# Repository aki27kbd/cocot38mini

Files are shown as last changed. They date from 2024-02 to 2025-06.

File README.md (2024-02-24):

# cocot38mini

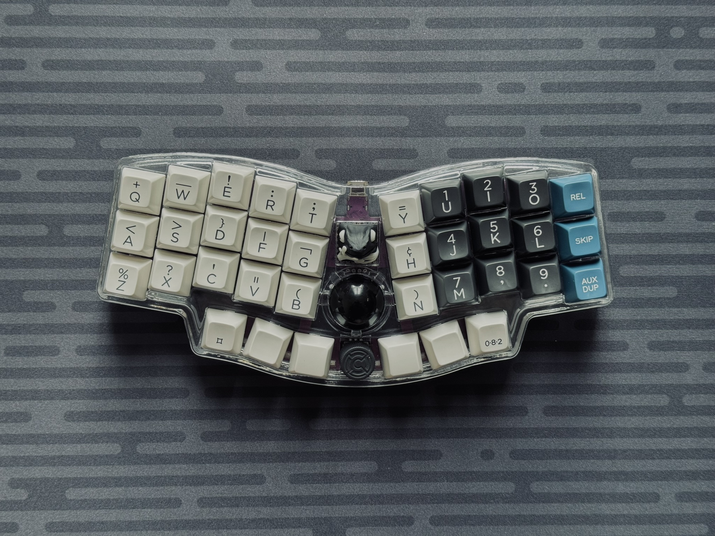
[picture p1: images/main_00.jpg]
cocot38mini_main00


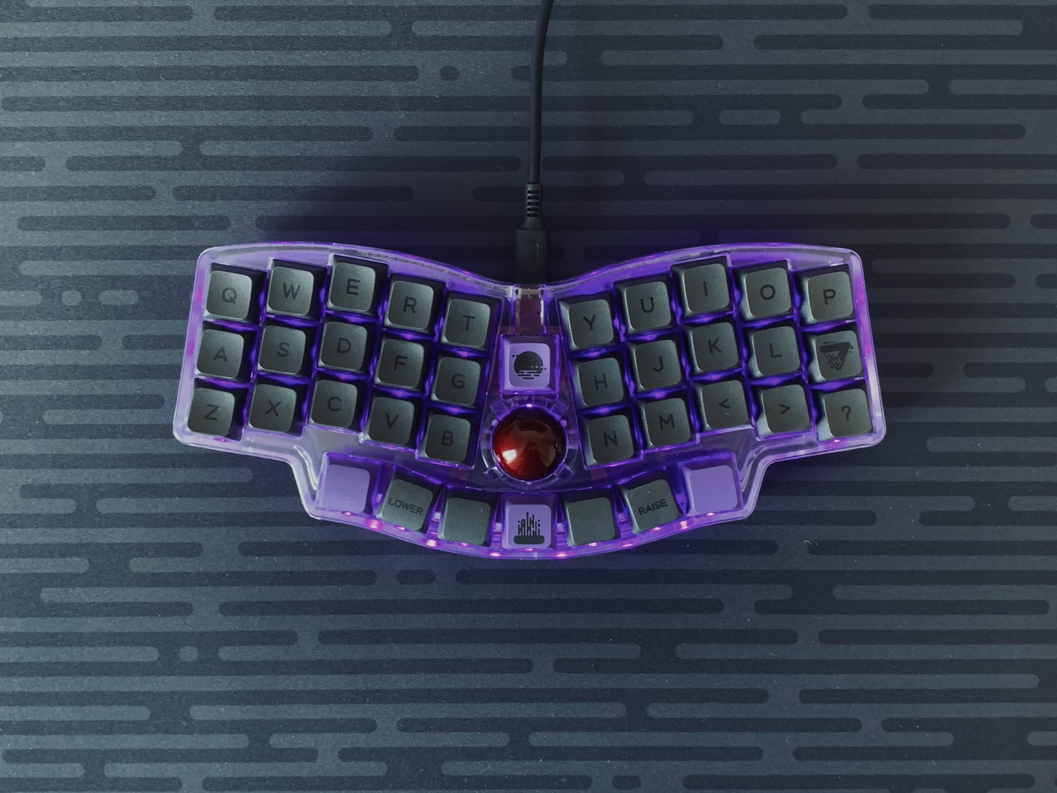
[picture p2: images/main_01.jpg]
cocot38mini_main01


cocot38mini is a compact column staggered keyboard with 38 keys and a 25mm-trackball.

- Keyboard Maintainer: [aki27kbd](https://github.com/aki27kbd) [@aki27kbd](https://twitter.com/aki27kbd)
- Hardware Supported: cocot38mini PCB
- Hardware Availability: [cocotkeebs](https://cocotkeebs.com)

Build Guide [JP](doc/buildguide.md) / [EN](doc/buildguide_en.md)

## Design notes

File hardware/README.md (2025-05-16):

# cocot38mini Case Guide

cocot38miniはマウント方式、ボール保持方式、ボール支持方式に応じて様々な種類のケースオプションを用意しています。このガイドにある各種方式の説明を参考に、お好みのケースを作成してください。

cocot38mini_main00

# Mounting Method

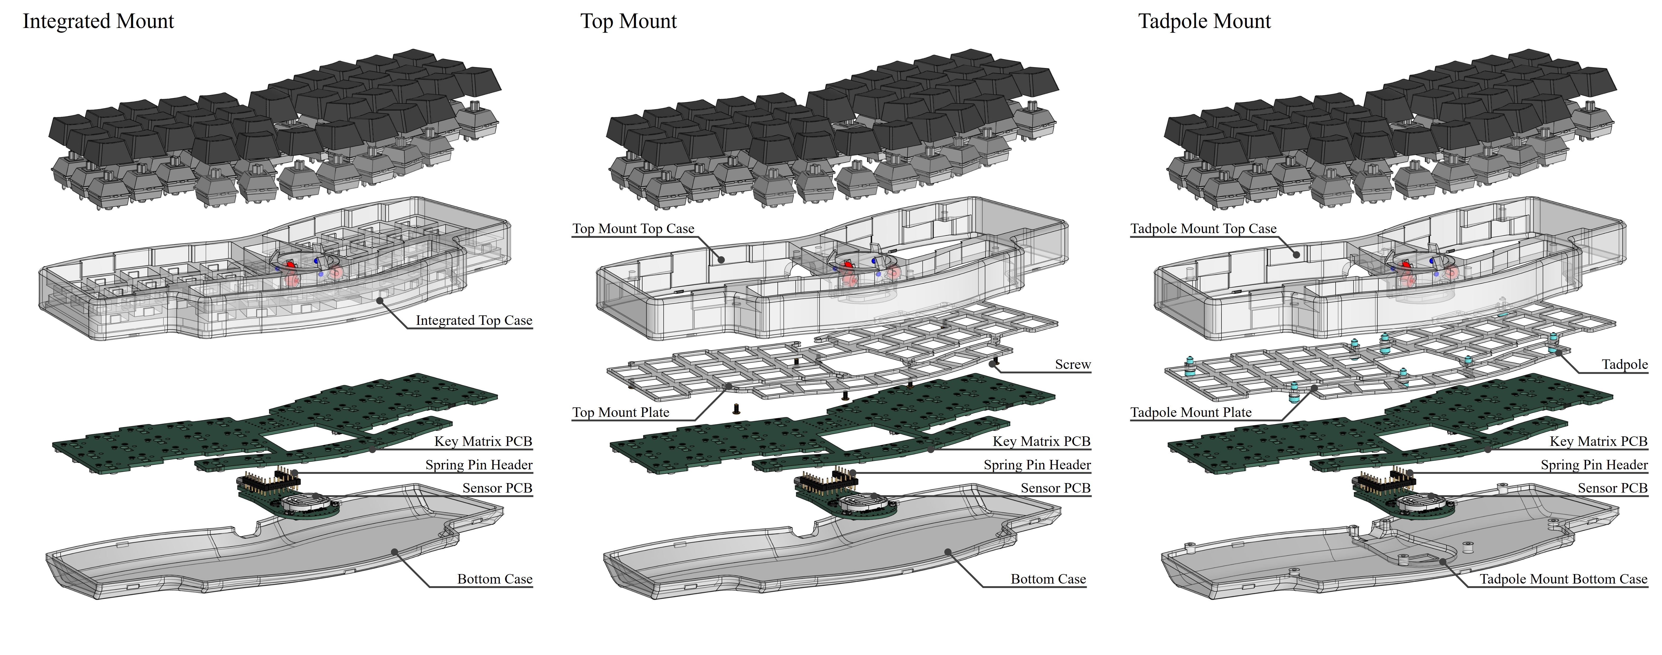
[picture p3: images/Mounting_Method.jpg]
mounting_method


### Integrated
プレートインテグレーテッドマウントは部品点数が最も少ない方式です。プレートの厚みが5mmでかつケース構造と一体化されているので、比較的硬い打鍵感となっています。

|Parts|Qty|Note|
|---|---|---|
|3Dプリントトップケース|1|"_integrated"が含まれるトップケース|
|3Dプリントボトムケース|1|cocot38mini_v2_bottom.stp|

### Top Mount
トップマウントはプレートをトップケースにねじ止めする方式です。トップケースに熱圧入インサートナットを埋め込む必要があるので、組み立て難易度は比較的高めです。プレートの材質や厚みを変更することで打鍵感を調整することが可能です。   
**熱圧入インサートナットはSLA（レジン）への固定に適しません。レジンのケースを作成する場合は、接着剤等でインサートナットを固定してください。**

|Parts|Qty|Note|
|---|---|---|
|3Dプリントトップケース|1|"_topmount"が含まれるトップケース|
|3Dプリントスイッチプレート|1|"_topmount"が含まれるプレート|
|3Dプリントボトムケース|1|cocot38mini_v2_bottom.stp|
|熱圧入インサートナット|8|[HFB-2001](https://hirosugi.co.jp/products/B/HFB.html#bx1)|
|M2ねじ3mm|8||

### Tadpole Mount
タッドポールマウントはシンプルな構造と良好な打鍵感のバランスが特徴の方式です。タッドポールの硬さを変更することで打鍵感の調整が可能です。

|Parts|Qty|Note|
|---|---|---|
|3Dプリントトップケース|1|"_tadpole"が含まれるトップケース|
|3Dプリントスイッチプレート|1|"_tadpole"が含まれるプレート|
|3Dプリントボトムケース|1|cocot38mini_v2_tadpole_bottom.stp|
|Tadpole|8|Available at [GEONWORKS](https://geon.works/products/tadpole) or [GREENKEYS](https://shop.green-keys.info/products/tadpole)|

# Ball Supporting Method

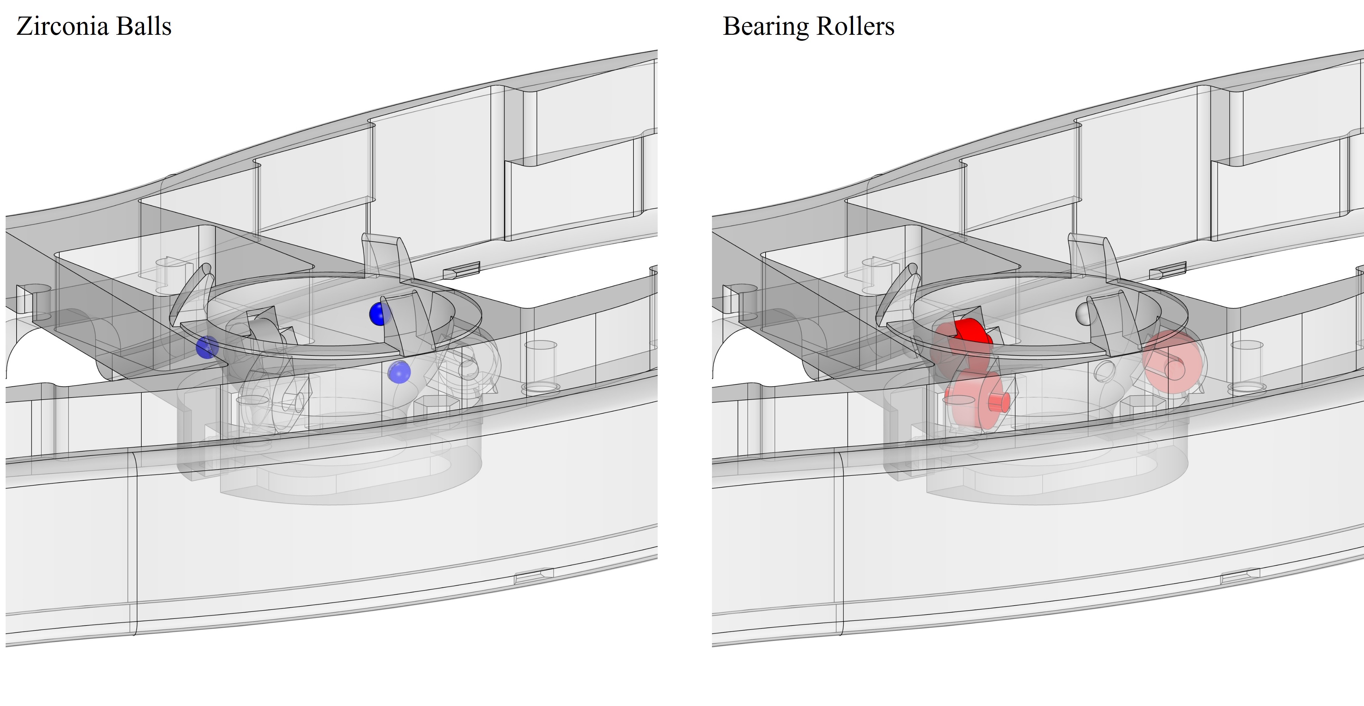
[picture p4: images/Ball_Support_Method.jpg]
ball_support_method


### Zirconia Balls
2mmジルコニア球によるボール支持方式です。キットにジルコニア球が含まれている場合、追加のバーツは必要ありません。ジルコニア球を接着剤で固定した場合、ベアリングとの共存はできません。

|Parts|Qty|Note|
|---|---|---|
|ジルコニア球|3|Φ2mm|

### Bearing Rollers
ベアリングローラーによるボール支持方式です。スムーズな操球が可能です。   
組み立て方法は[picot5400](https://github.com/aki27kbd/picot5400/blob/main/doc/buildguide.md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)を参照してください。

|Parts|Qty|Note|
|---|---|---|
|ベアリングローラー|3|ID:3mm x OD:6mm x W:2.5mm|
|ステンレス棒|3|Φ2mm x L:6mm|
|シリコンチューブ|1|ID: 2mm x OD:3mm|

# Ball Holding Method

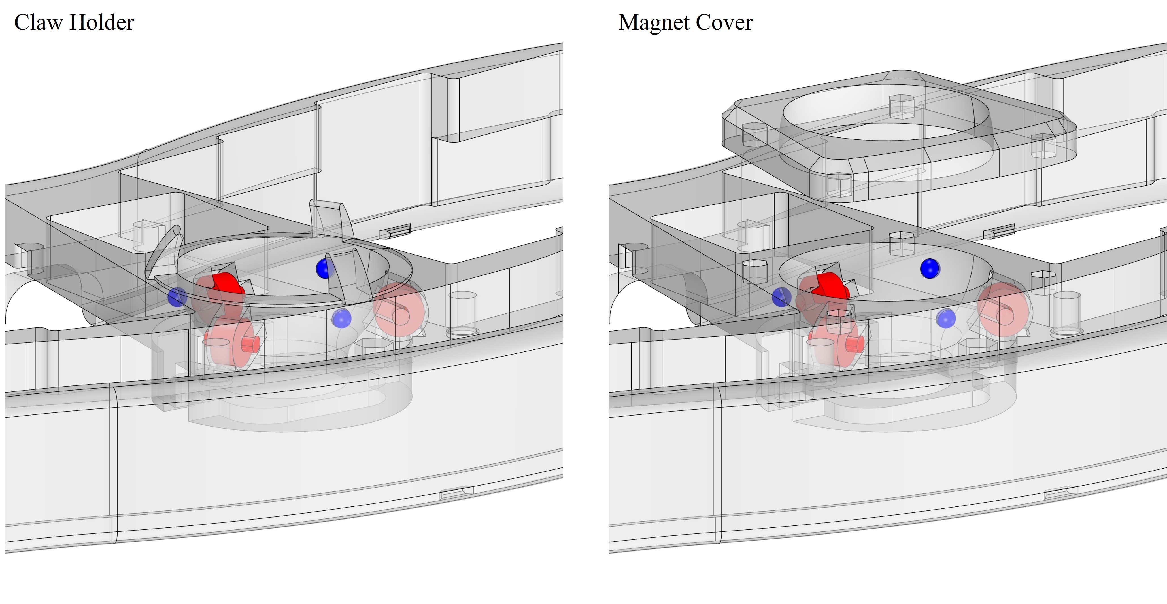
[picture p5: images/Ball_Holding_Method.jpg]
ball_holding_method


### Claw Holder
3本のツメでボールが落下しないようにするケースです。  
**FDM方式のプリンターでケースを作成した場合、ツメが破損しやすくなるためお勧めいたしません。**

|Parts|Qty|Note|
|---|---|---|
|3Dプリントトップケース|1|"_claw"が含まれるトップケース|

### Magnet Cover
マグネットによってボールカバーをトップケースに固定する方式です。容易にボールの取り外しが可能です。

|Parts|Qty|Note|
|---|---|---|
|3Dプリントトップケース|1|"_magnet"が含まれるトップケース|
|3Dプリントボールカバー|1|cocot38mini_v2_ballcover.stp|
|マグネット|8|Φ3mm x H:2mm|

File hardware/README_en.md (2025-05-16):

# cocot38mini Case Guide

cocot38mini provides various case data depending on mounting methods, ball support styles and ball holding geometries. This guide shows the overview of each method, including pros/cons as well as BOM of it.

cocot38mini_main00

# Mounting Method

mounting_method

### Integrated
Plate-integrated mount is the simplest mounting method with fewer parts required to assemble. No additional parts are required to build this case. As the plate is thick and integrated with the case structure, it provides a solid feeling relative to other mounting methods.

|Parts|Qty|Note|
|---|---|---|
|3D Printed Top Case|1|Top case named with "_integrated"|
|3D Printed Bottom Case|1|cocot38mini_v2_bottom.stp|

### Top Mount
Top mount is the general mounting method which is also used for some of custom keyboards. Assembly is relatively difficult due to the need of heated insert nuts. Typing softness can be adjusted depending on the plate material.   
**SLA (Resin) is not suitable for heated insert nut. If you use it as a case material, make sure you fix insert nuts with glue.**

|Parts|Qty|Note|
|---|---|---|
|3D Printed Top Case|1|Top case named with "_topmount"|
|3D Printed Switch Plate|1|Plate named with "_topmount"|
|3D Printed Bottom Case|1|cocot38mini_v2_bottom.stp|
|Heated Insert Nut|8|[HFB-2001](https://hirosugi.co.jp/products/B/HFB.html#bx1)|
|M2 Screw 3mm|8||

### Tadpole Mount
Tadpole mount is designed considering the balance of simple structure and better typing feel. Assembly is relatively easy as long as tadpoles are available. Typing softness can be adjusted depending on the hardness of tadpoles.

|Parts|Qty|Note|
|---|---|---|
|3D Printed Top Case|1|Top case named with "_tadpole"|
|3D Printed Switch Plate|1|Plate named with "_tadpole"|
|3D Printed Bottom Case|1|cocot38mini_v2_tadpole_bottom.stp|
|Tadpole|8|Available at [GEONWORKS](https://geon.works/products/tadpole) or [GREENKEYS](https://shop.green-keys.info/products/tadpole)|

# Ball Supporting Method

ball_support_method

### Zirconia Balls
3x Φ2mm zirconia balls support the ball. No additional parts needed. Once zirconia balls are installed, <u>**bearing rollers can not coexist with them**</u>.

|Parts|Qty|Note|
|---|---|---|
|Zirconia Ball|3|Φ2mm|

### Bearing Rollers
3x bearing rollers support the ball. Ball handling is smoother with less resistance. Bearing roller dimension is ID: 3mm / OD: 6mm / W: 2.5mm.　　　
Refer to [picot5400](https://github.com/aki27kbd/picot5400/blob/main/doc/buildguide_en.md#ball-case) for assembly.

|Parts|Qty|Note|
|---|---|---|
|Bearing Roller|3|ID:3mm x OD:6mm x W:2.5mm|
|Steel Pin|3|Φ2mm x L:6mm|
|Silicon Tube|1|ID: 2mm x OD:3mm|

# Ball Holding Method

ball_holding_method

### Claw Holder
Claw holder is integrated with the top case and no additional parts needed. Due to the thin structure, it is <u>**not recommended**</u> printing this model with FDM printers.

|Parts|Qty|Note|
|---|---|---|
|3D Printed Top Case|1|Top case named with "_claw"|

### Magnet Cover
Magnet cover is an additional part attached to the top case with magnets. Depending on case clearance, glue might be needed to fix magnets.

|Parts|Qty|Note|
|---|---|---|
|3D Printed Top Case|1|Top case named with "_magnet"|
|3D Printed Ball Cover|1|cocot38mini_v2_ballcover.stp|
|Magnet|8|Φ3mm x H:2mm|

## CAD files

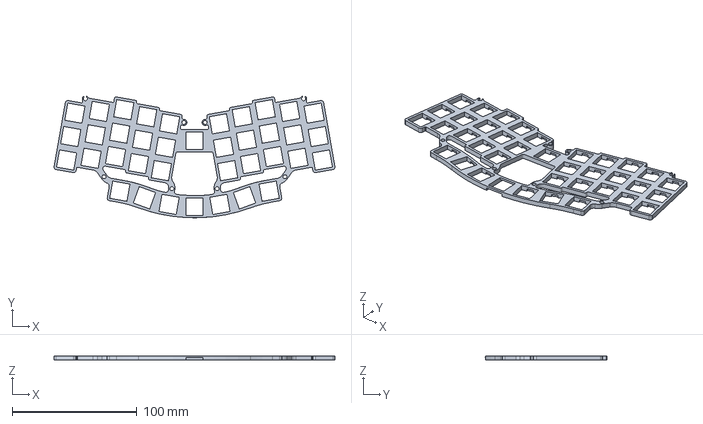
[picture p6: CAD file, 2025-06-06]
hardware/cocot38mini_v2_tadpole_plate_thick.stp
225.0 x 97.4 x 3.50 mm

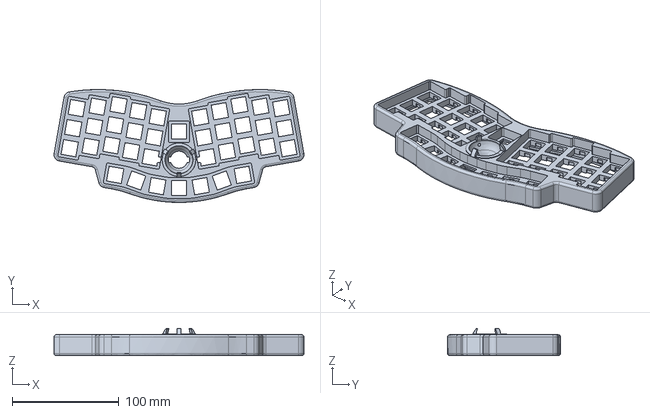
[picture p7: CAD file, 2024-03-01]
hardware/v1/cocot38mini_top_v1.stp
234.2 x 105.7 x 25.5 mm

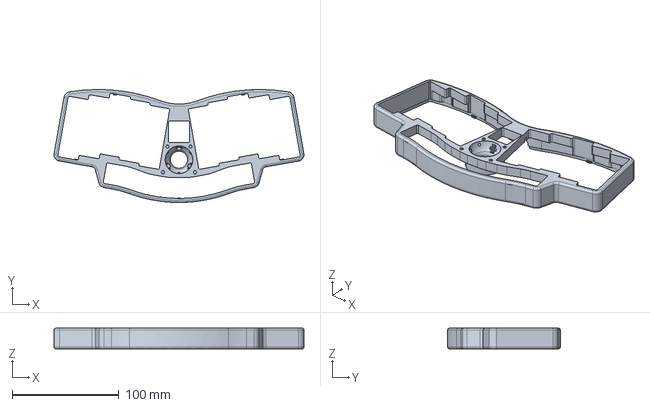
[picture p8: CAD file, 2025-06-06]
hardware/cocot38mini_v2_tadpole_top_magnet_Lsnap.stp
234.2 x 105.8 x 19.6 mm

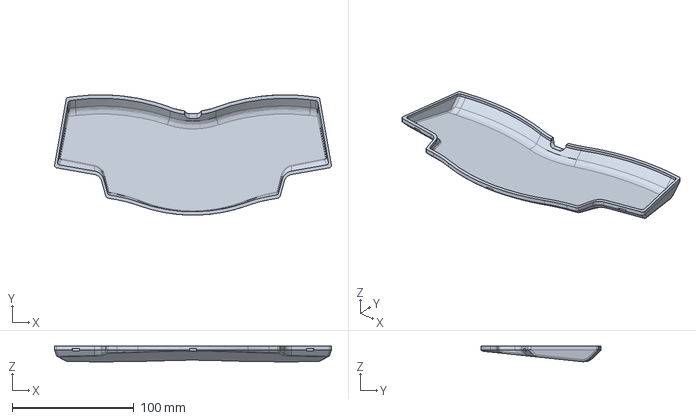
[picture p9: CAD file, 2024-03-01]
hardware/v1/cocot38mini_bottom_v1.stp
227.4 x 98.8 x 12.8 mm

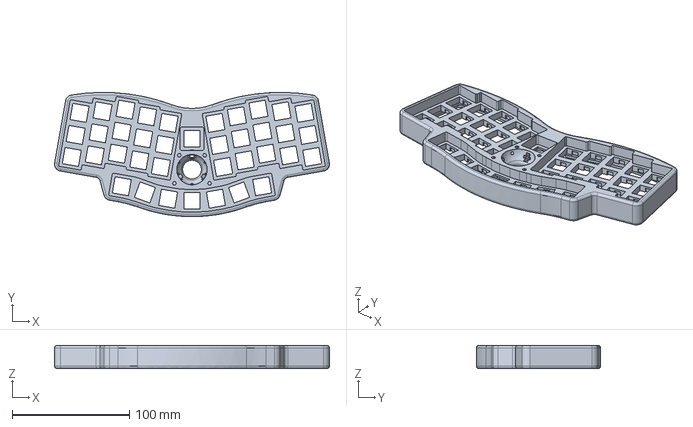
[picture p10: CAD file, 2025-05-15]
hardware/cocot38mini_v2_integrated_top_magnet.stp
234.2 x 105.8 x 19.6 mm

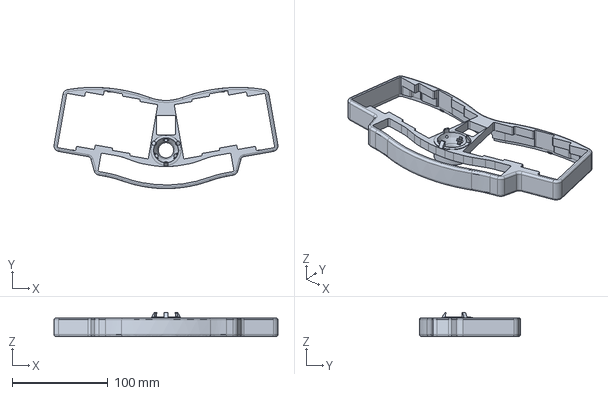
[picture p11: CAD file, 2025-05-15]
hardware/cocot38mini_v2_topmount_top_claw.stp
234.2 x 105.7 x 25.2 mm

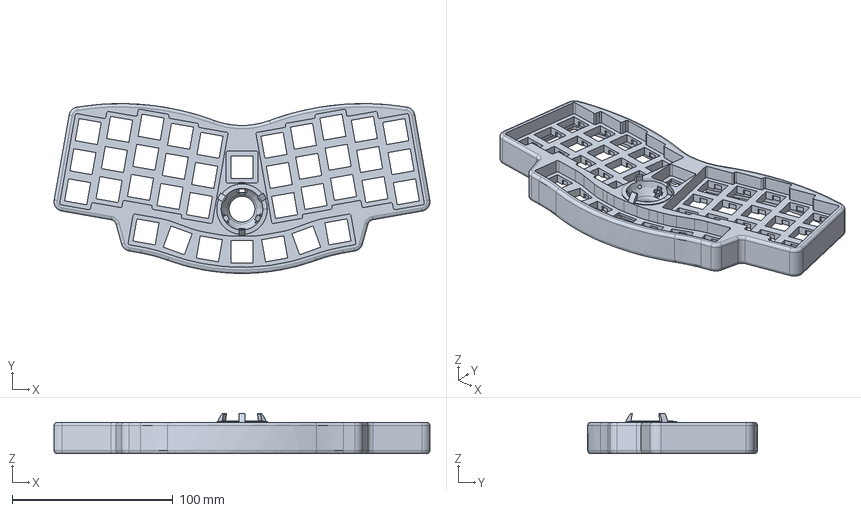
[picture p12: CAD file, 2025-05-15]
hardware/cocot38mini_v2_integrated_top_claw.stp
234.2 x 105.7 x 25.2 mm

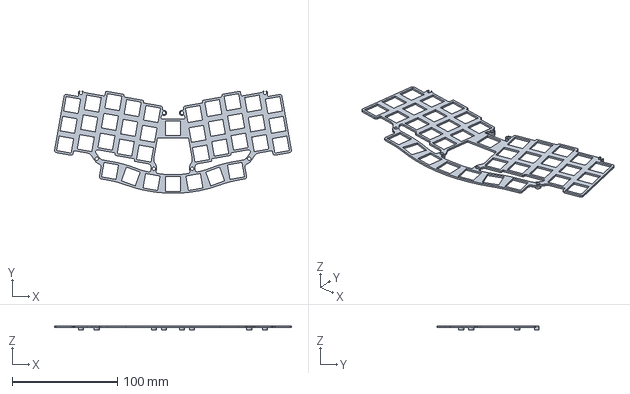
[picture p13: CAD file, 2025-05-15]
hardware/cocot38mini_v2_tadpole_plate.stp
225.0 x 97.3 x 3.50 mm

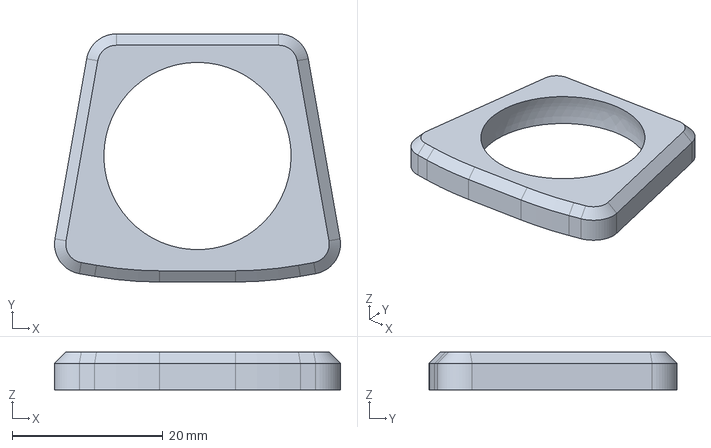
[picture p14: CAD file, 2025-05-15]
hardware/cocot38mini_v2_ballcover.stp
38.0 x 33.0 x 5.00 mm

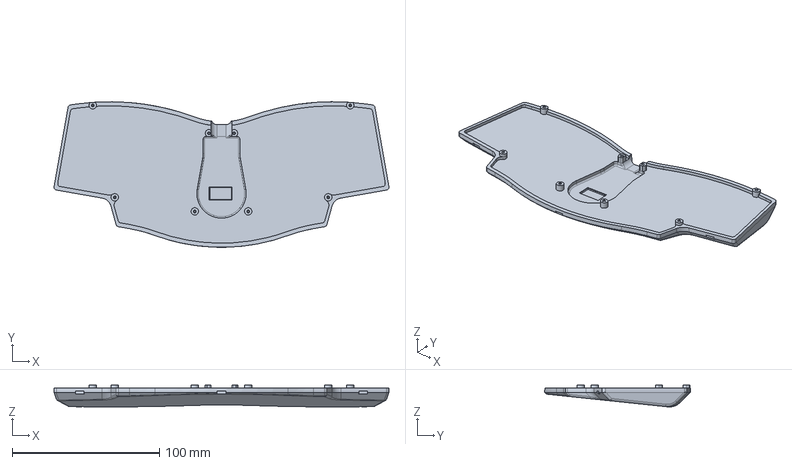
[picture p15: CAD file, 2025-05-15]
hardware/cocot38mini_v2_tadpole_bottom.stp
227.4 x 98.8 x 14.8 mm

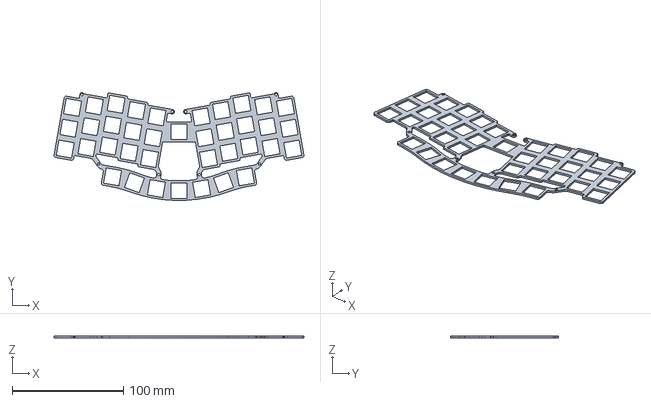
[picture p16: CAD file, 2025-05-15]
hardware/cocot38mini_v2_topmount_plate.stp
225.0 x 97.0 x 1.50 mm

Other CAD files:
hardware/cocot38mini_v2_bottom.stp
hardware/cocot38mini_v2_topmount_top_magnet.stp
hardware/cocot38mini_v2_tadpole_top_claw.stp
hardware/cocot38mini_v2_tadpole_top_magnet.stp

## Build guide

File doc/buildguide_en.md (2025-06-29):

# Build Guide

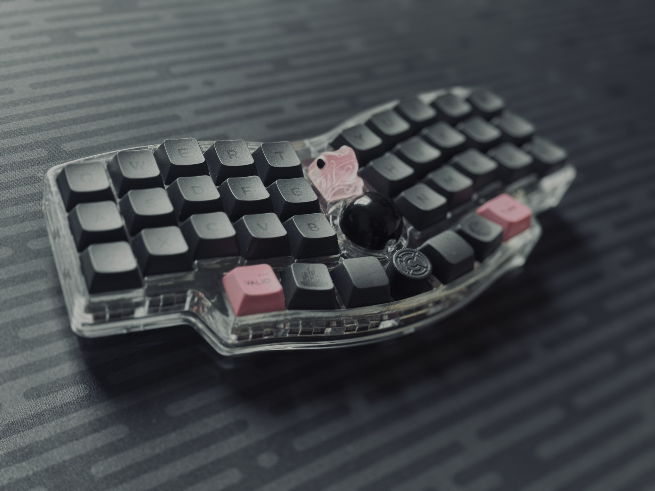
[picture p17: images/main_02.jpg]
cocot38mini_main02


This is a buildguide for cocot38mini v2.  
For v1 buildguide, refer to the previous documents ([JP](v1/buildguide.md) / [EN](v1/buildguide_en.md))

cocot38mini is designed as a more compact version of cocot series, with column-staggered 38 keys, 25mm trackbvall and 3D printed case. To begin with, please make sure you read this buildguide carefully and you have everything you need before you start to asseble.

## Parts
### Parts Included

|Parts|Qty|Notes|
|---|---|---|
|PCB|1||
|Sensor PCB|1||
|Sensor (PMW3360)|1||
|Rubber Feet|4||
|Zirconia Balls (2mm)|3||

### Additional Required Parts

|Parts|Qty|Notes|
|---|---|---|
|3D Printed Case (Top+Bottom)|1|You can download 3d data to order 3d printing service by yourself|
|Keyswitch|37 or 38|MX|
|Keycap|37 or 38|MX|
|Rotary Encoder + Knob |1|Optional|
|Spring Pin Header or Pin Header (H2.5mm)|At least 20 pins are necessary||
|25mm Trackball|1||
|Bearing Roller|3|Optional (Bearing Roller Support)|
|Tadpole|8|Optional (Tadpole Mount)|
|Heated Insert Nut|8|Optional (Top Mount)|
|M2 Screw 3mm|8|Optional (Top Mount)|
|USB-Type C Cable|1||

## Assembly
### Parts Check

  First, please make sure that you have all the parts listed above. If the PCB comes with tabs, break off the tabs and lightly file the cut surfaces.

### Firmware

  It is delivered with the default firmware is written. Before starting soldering, make sure you confirm the sensor PCB is recognized as cocot38mini when you plug USB to it.

  If you wish to write your own firmware, please follow the instructions below.

  - Press the RESET button (SW39) while holding down the BOOT button (SW40) on the bottom side to enter boot loader mode.
  - The firmware is written by dragging and dropping the [.uf2](https://github.com/aki27kbd/cocot38mini/blob/main/firmware/aki27_cocot38mini_v2_vial.uf2) file into the drive named RPI-RP2.  
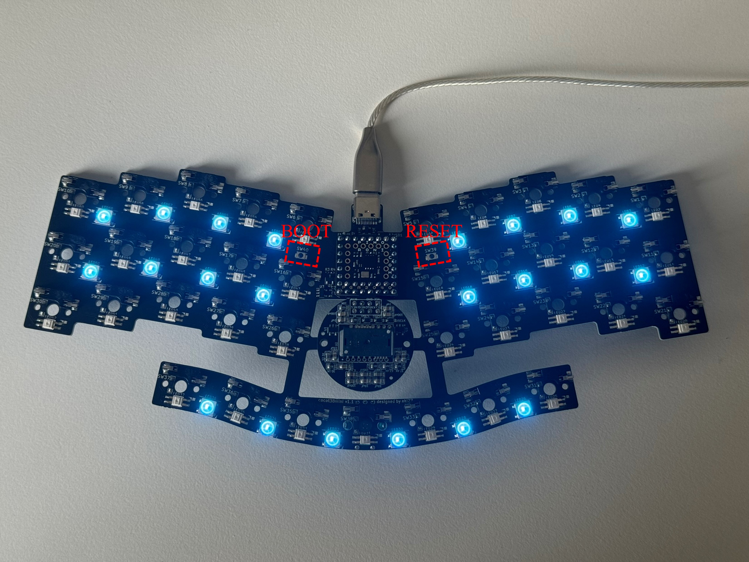
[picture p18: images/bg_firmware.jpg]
    

  Keymap is editable from [vial](https://vial.rocks/).  
  You can confirm that trackball and LEDs are working correctly with this firmware. You can confirm the trackball move after you assemble the following steps.

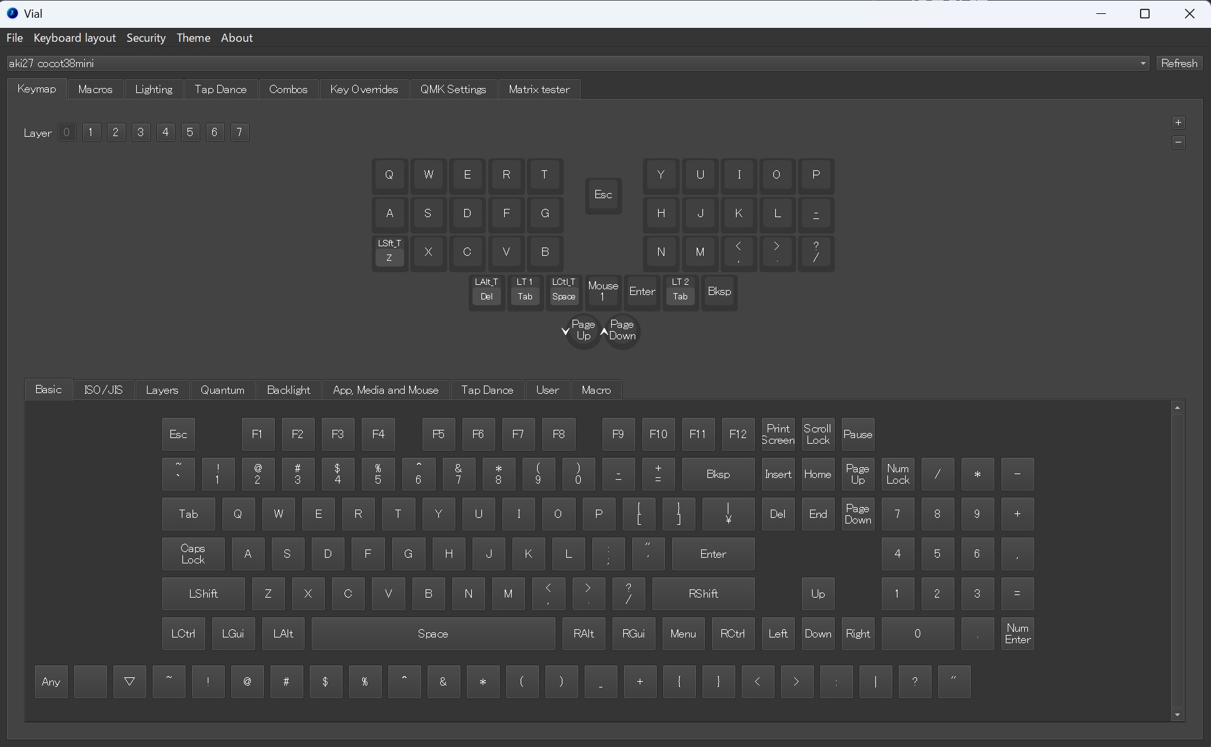
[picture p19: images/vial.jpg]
vial
  

  The default firmware enables "Auto Mouse Layer", with which you can automatically jump into a specific mouse layer when you move trackball. You can toggle on/off this function with the custom keycode `AM_TOG`.

  The source code is available [here](https://github.com/aki27kbd/vial-qmk/tree/vial/keyboards/aki27/cocot38mini).

### Sensor PCB

  Place the mouse sensor (PMW3360) on the sensor board in the orientation shown in the picture. Please make sure to align the ● mark on the silk with the ● mark on the board.
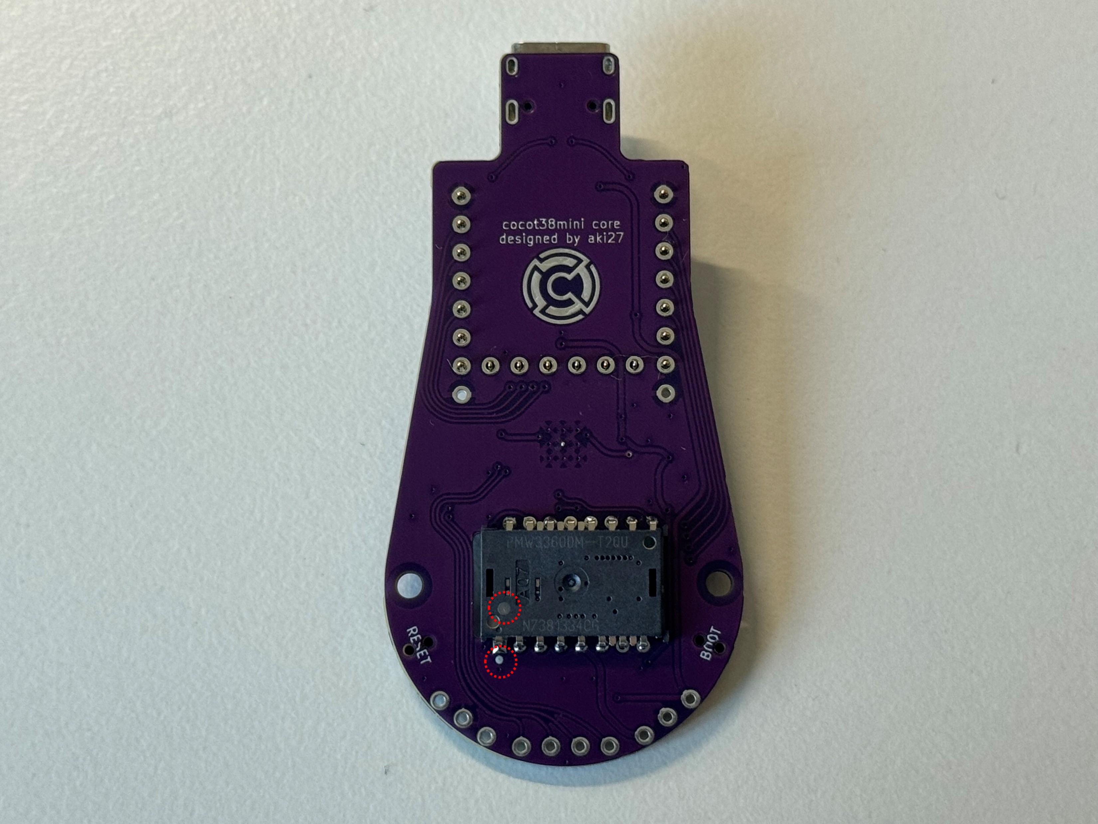
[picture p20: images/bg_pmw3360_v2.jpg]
  

  With the sensor pins firmly in place, secure them with tape so that they do not float. Solder 16 pins from the top side. Remove tape from the sensor and attach the lens from the top side.   
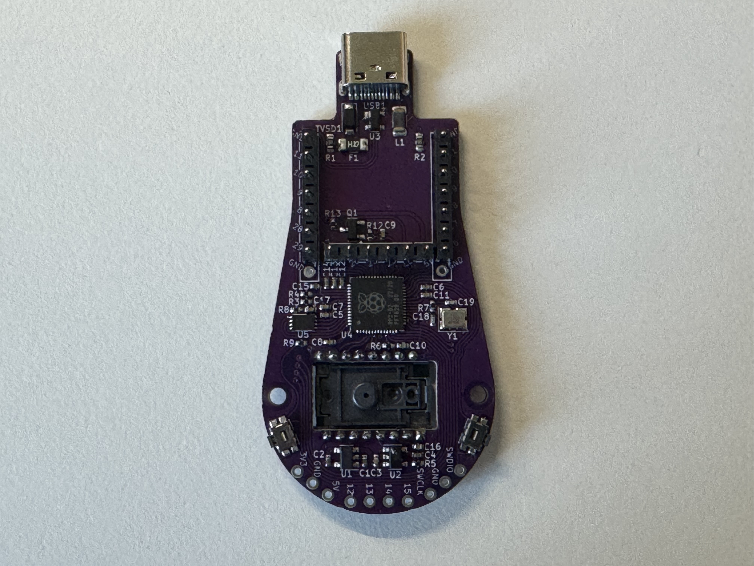
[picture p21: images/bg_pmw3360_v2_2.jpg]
  

  Once you finish soldering, please confirm that mouse cursor moves when you move close to the sensor.

### Spring Pin Header

  In this buildguide spring pin headers are used as example, but you can follow the most steps when you use pin headers.

  Cut spring pin headers with a cutter knife and insert them into the top side of the sensor PCB as shown in the picture below. The picture shows 2x7pins and 1x6pins as example. Please make sure you insert them in the correct location.  
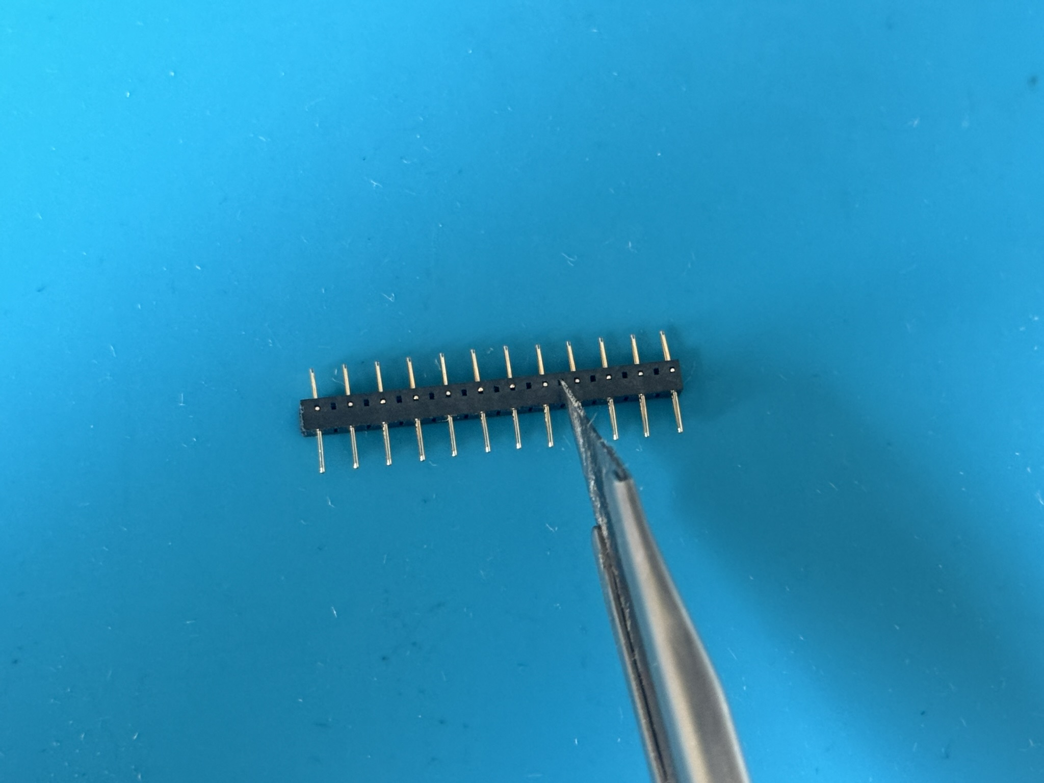
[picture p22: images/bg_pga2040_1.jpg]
  

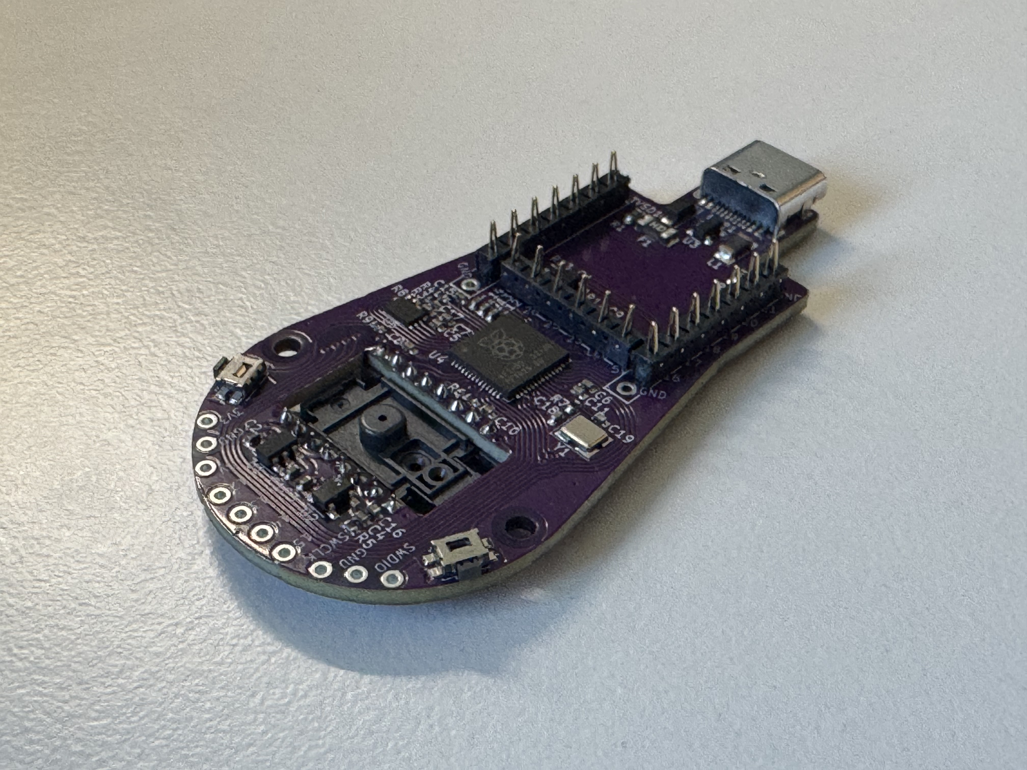
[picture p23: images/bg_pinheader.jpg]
  

  Once you insert spring pin headers to the PCB, insert main PCB onto it. ***Pay close attention to the orientation of each PCB.***  
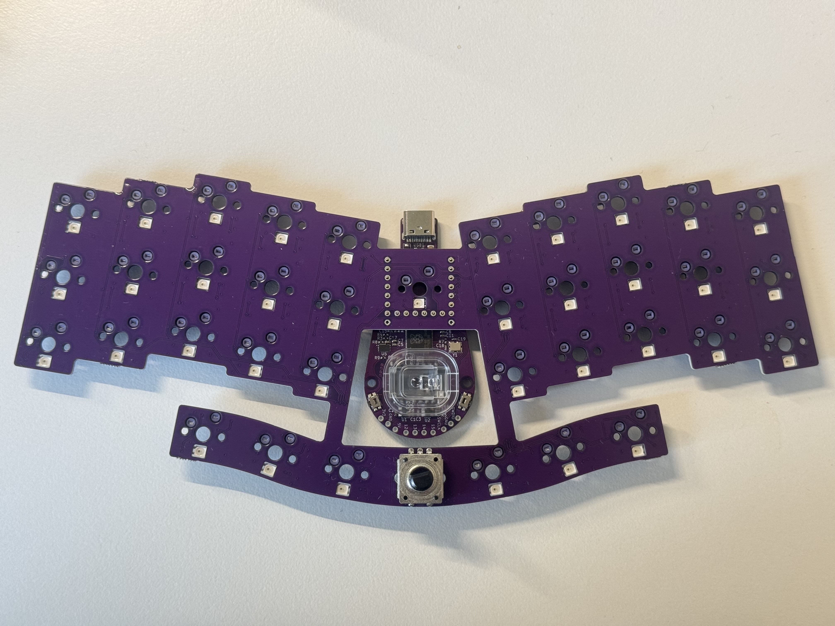
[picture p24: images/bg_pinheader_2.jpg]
  

### Rotary Encoder (optional)

  If you prefer to using rotary encoder at the center of thumb clusters, insert a rotary encoder in the position shown in the picture and solder 5 pins from the bottom side.
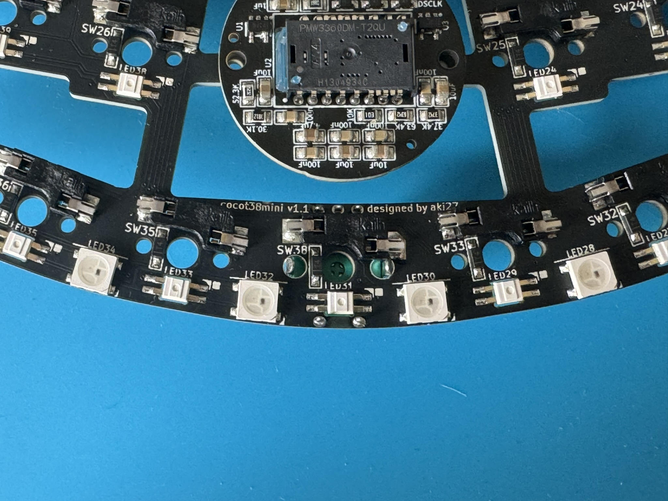
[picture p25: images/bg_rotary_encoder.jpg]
  

### Zirconia Balls

  Glue the zirconia balls to the 3D printed top case using a two-component epoxy glue.  
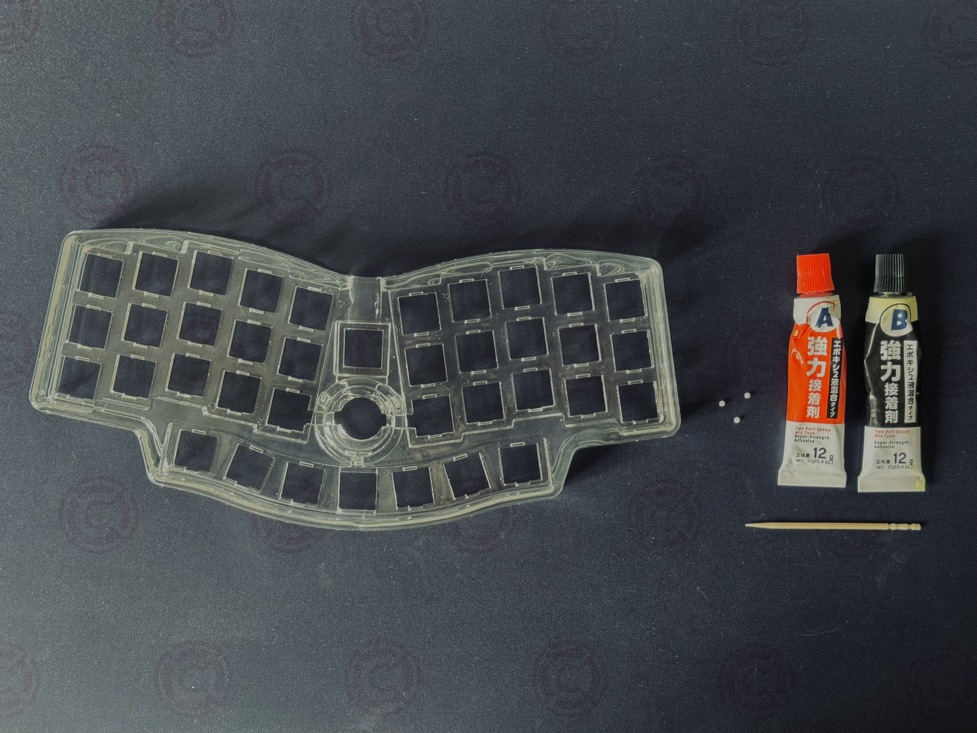
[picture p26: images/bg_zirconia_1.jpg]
  

  Take a small amount of glue on the tip of a toothpick or similar tool and apply it to the three depressions on the top case.  
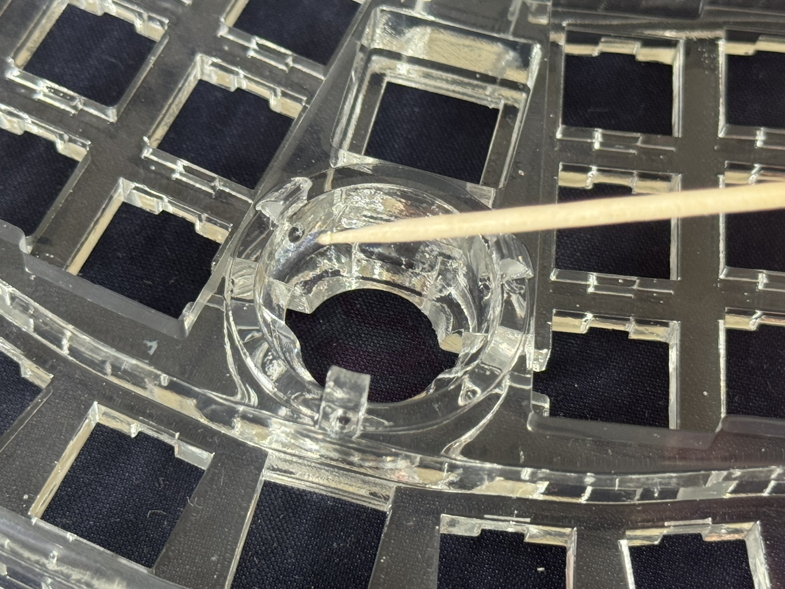
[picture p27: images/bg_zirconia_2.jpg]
  

  Insert zirconia balls into the depressions with glue and leave them until they harden. If the glue overflows into the surrounding area, wipe it off before it hardens. After the zirconia balls are glued, it will look like the picture below.  
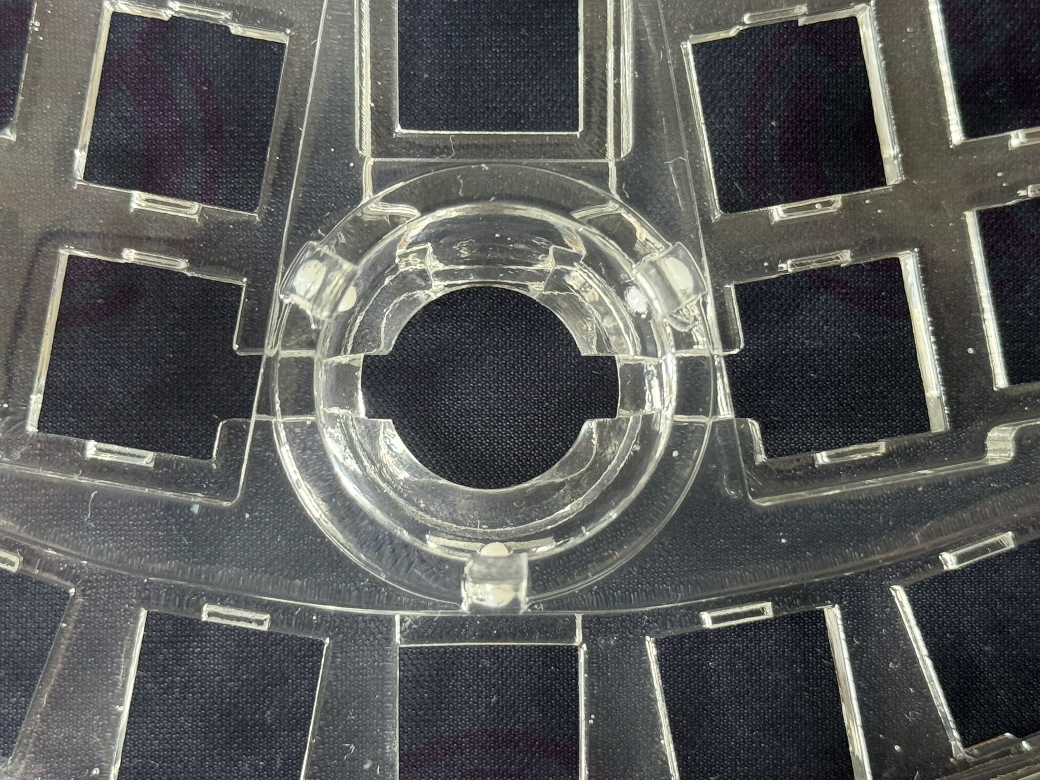
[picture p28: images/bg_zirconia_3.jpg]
  

### Assembly

  After soldering, stack the top case on top of the PCB and put key switches from the corners. Pay attention not bend the pins of the key switches.  
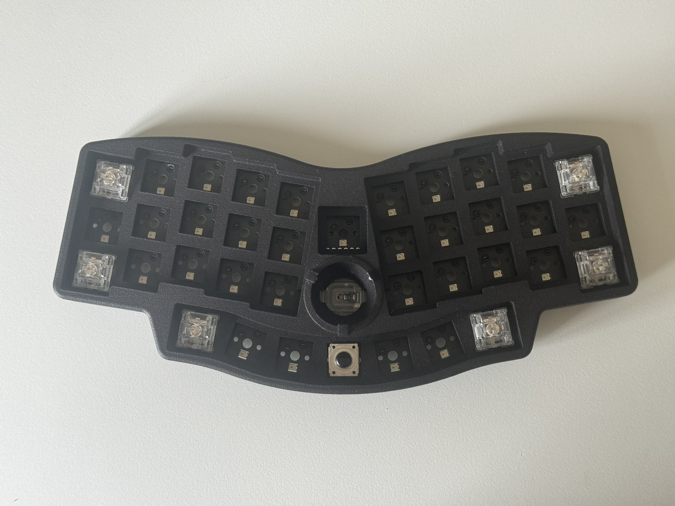
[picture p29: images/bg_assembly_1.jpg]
  

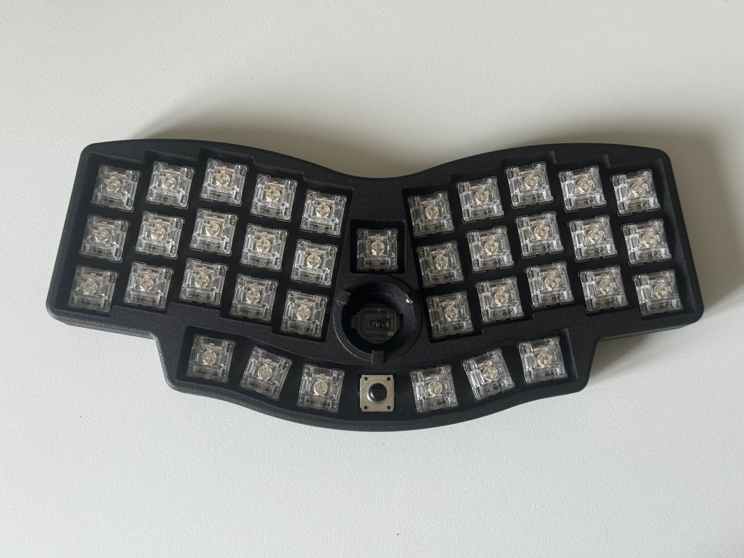
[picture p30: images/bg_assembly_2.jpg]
  

  Fit the top case and the bottom case together. First, align the bottom case so that the grooves on the bottom side of it (1&2) engages with the top case.  
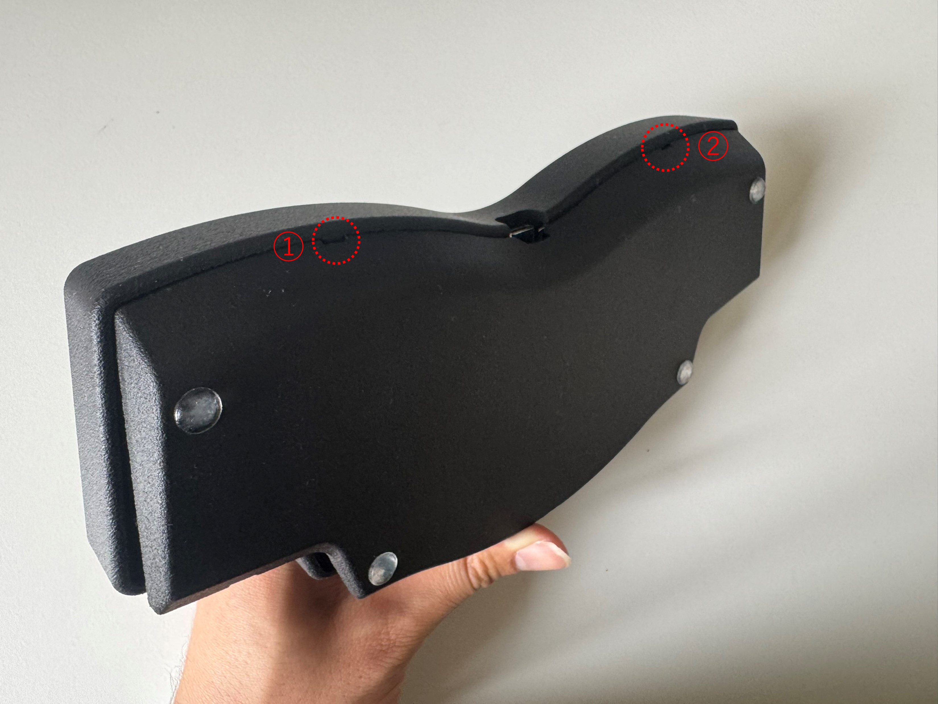
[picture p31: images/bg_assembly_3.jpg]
  

  FIt the remaining grooves into the top case. Push in the order of 3>4>5 until they snap into the place. It will be easier to fit the bottom case into the top case if you push it while pulling the bottom case toward the far side.
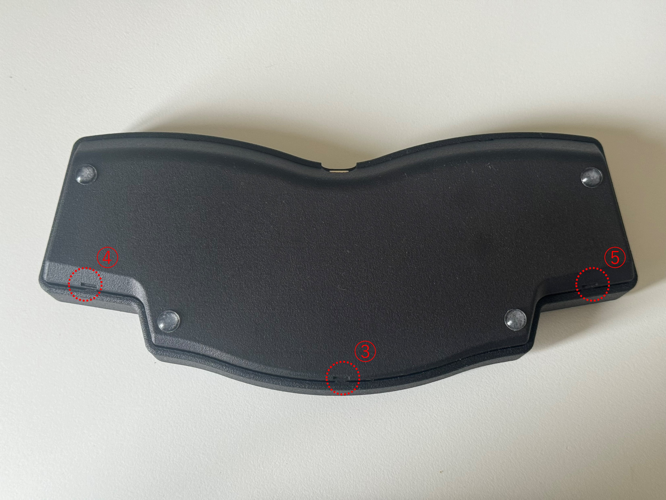
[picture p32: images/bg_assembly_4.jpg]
  

  Put rubber feet on the bottom case.
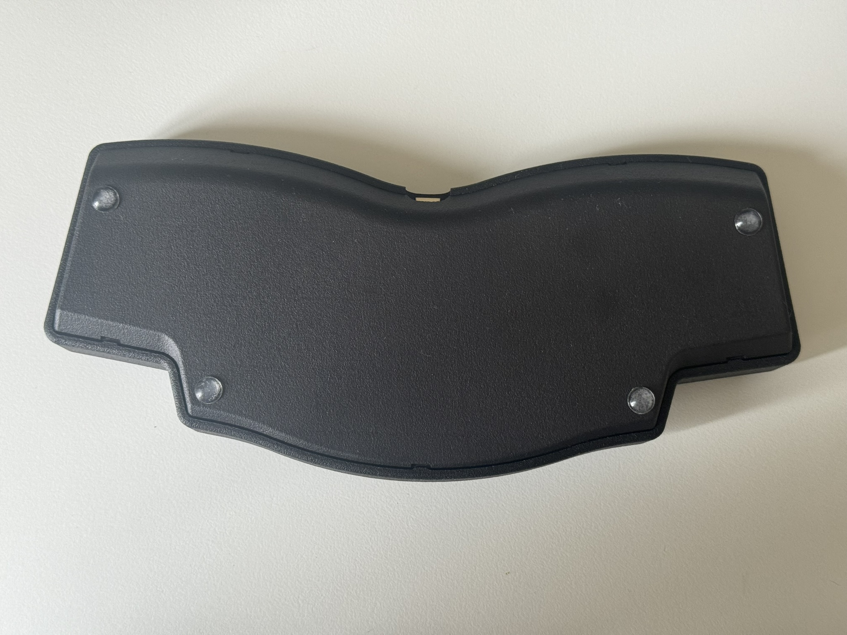
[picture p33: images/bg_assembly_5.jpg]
  

  Put ball and keycaps, and take a photo.
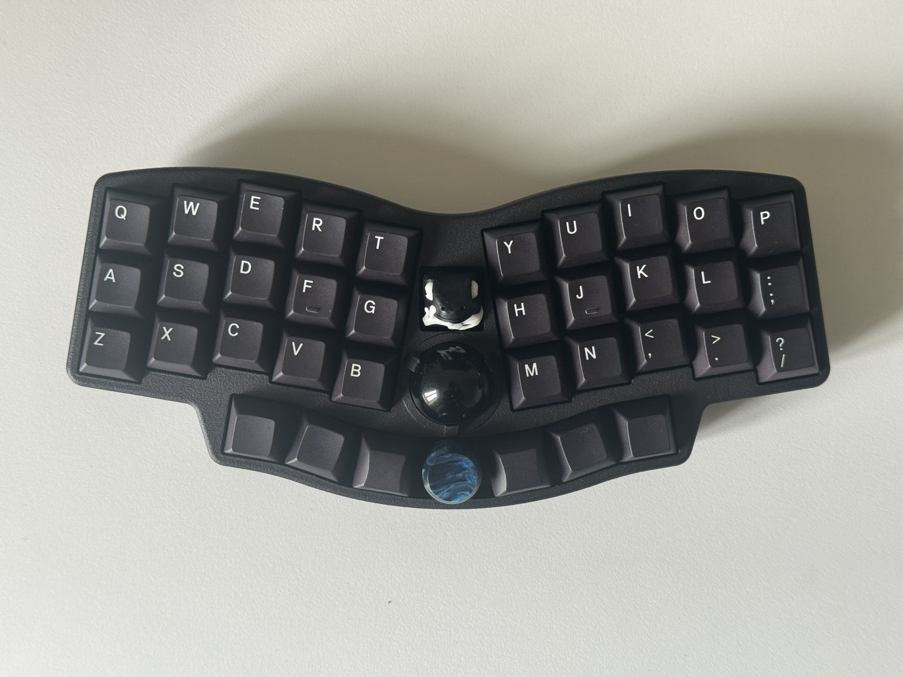
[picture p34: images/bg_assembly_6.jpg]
  

## Custom Keycodes

  Several custom key codes can be set for trackball operation.

  Keycode   |Description
  ---------|-----------
  `CPI_SW`  |Change the CPI of the trackball. With the default firmware, each press changes the CPI in the following order: 200 -> 400 -> 800 -> 1600 -> 3200 -> 200....
  `SCRL_SW` |Changes the sensitivity of the sensor in scroll mode. The higher the value, the smaller the amount of scrolling.
  `ROT_R15` |Turns the Y axis of the mouse sensor 15 degrees clockwise.
  `ROT_L15` |Rotate the Y axis of the mouse sensor 15 degrees counterclockwise.
  `SCRL_MO` |	Enables scroll mode for as long as it is pressed.
  `SCRL_TO` |Toggles between scroll mode and mouse mode each time it is pressed.
  `SCRL_IN` |Inverts the scroll direction.
  `AM_TOG` |Toggle the function of auto mouse layer.

  Custom key codes can be set in vial using the custom key code under the User tab.  
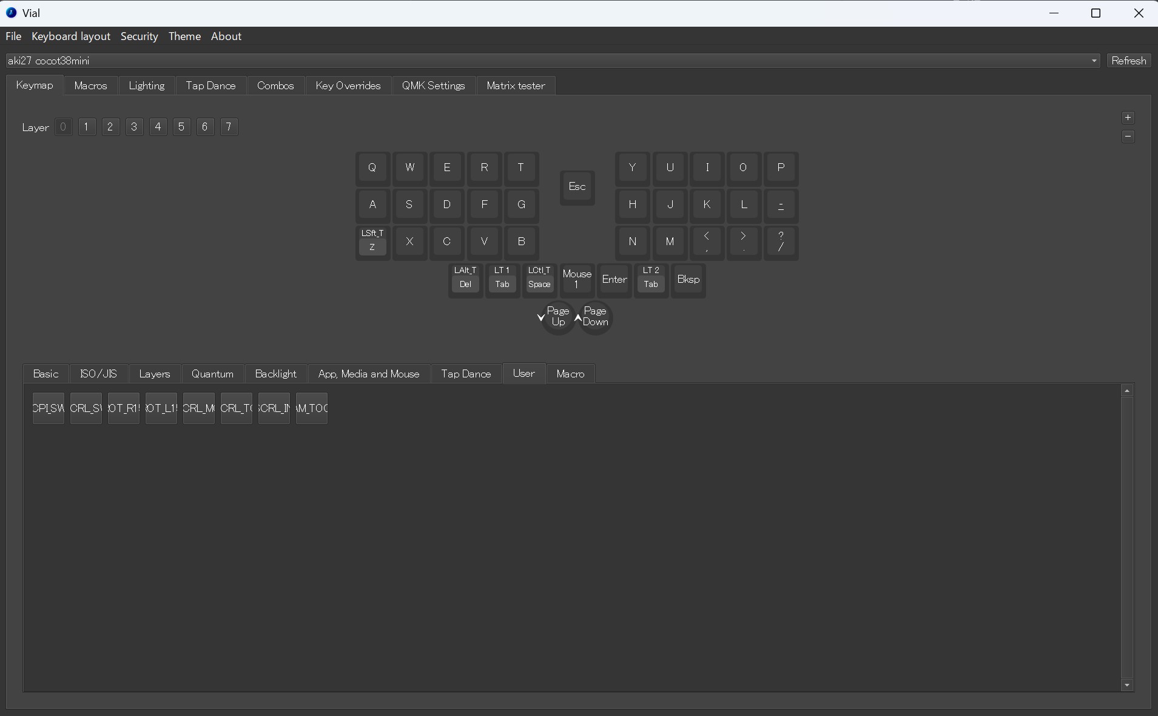
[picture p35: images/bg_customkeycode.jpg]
CustomKeycode_rev
  

## Notes
If you have any problems, please contact us at[Twitter](https://twitter.com/aki27kbd).

Also, it would be very encouraging if you could upload the completed photos to social networking sites. (If you don't feel comfortable uploading your photos, you can send them directly to us via DM.)

The hashtag is #cocot38mini .

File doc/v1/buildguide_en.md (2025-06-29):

# Build Guide

cocot38mini_main02

This is a buildguide for cocot38mini v1.  
For v2 buildguide, refer to the latest documents ([JP](/doc/buildguide.md) / [EN](/doc/buildguide_en.md))

cocot38mini is designed as a more compact version of cocot series, with column-staggered 38 keys, 25mm trackbvall and 3D printed case. To begin with, please make sure you read this buildguide carefully and you have everything you need before you start to asseble.

## Parts
### Parts Included

|Parts|No.|Notes|
|---|---|---|
|PCB|1||
|Sensor PCB|1||
|Sensor (PMW3360)|1||
|PGA2040|1||
|Rubber Feet|4||
|Zirconia Balls (2mm)|3||

### Additional Required Parts

|Parts|No.|Notes|
|---|---|---|
|3D Printed Case (Top+Bottom)|1|You can download 3d data to order 3d printing service by yourself|
|Keyswitch|37 or 38|MX|
|Keycap|37 or 38|MX|
|Rotary Encoder + Knob |1|Optional|
|Spring Pin Header or Pin Header (H2.5mm)|More than 42 pins are necessary||
|25mm Trackball|1||
|USB-Type C Cable|1||

## Assembly
### Parts Check

  First, please make sure that you have all the parts listed above. If the PCB comes with tabs, break off the tabs and lightly file the cut surfaces.

### PGA2040

  Solder spring pin headers (or pin headers) to the PGA2040. In this buildguide spring pin headers are used as example, but you can follow the most steps when you use pin headers.

  Cut spring pin headers with a cutter knife and insert them into the bottom side of the PCB as shown in the picture below. The picture shows 2x8pins and 3x6pins as example. Please make sure you insert them in the correct location.  
  cocot38mini_bg_

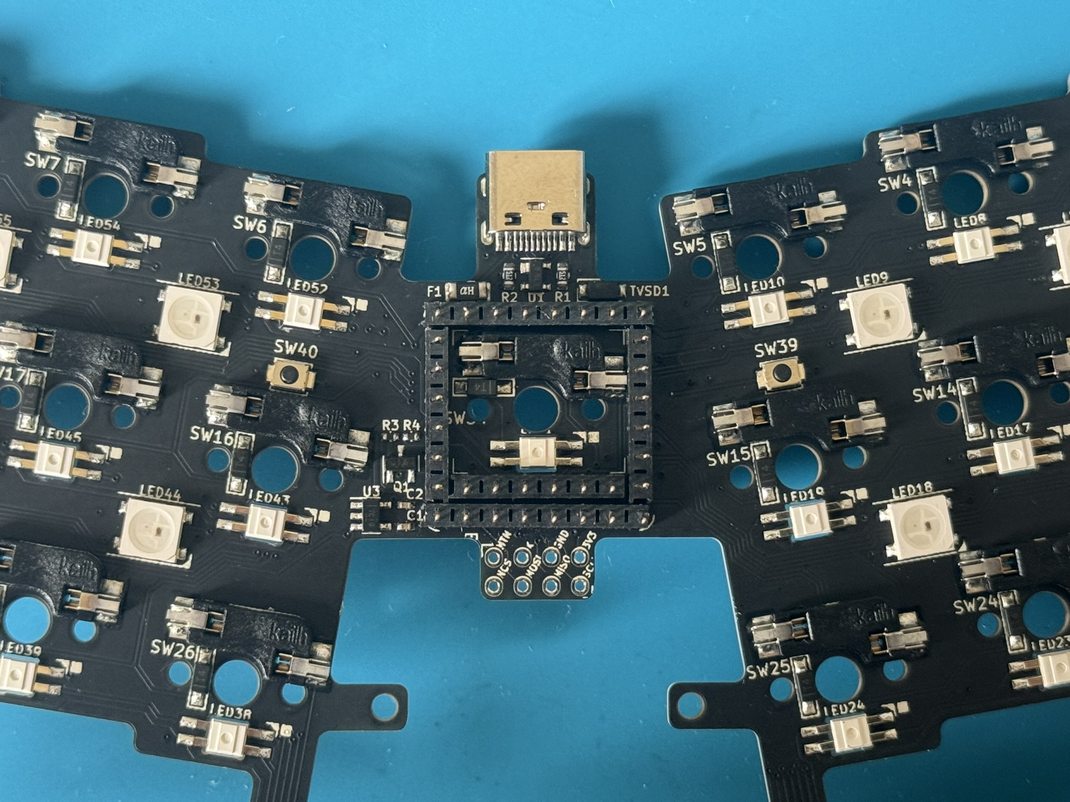
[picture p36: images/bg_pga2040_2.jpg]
  

  Once you insert spring pin headers to the PCB, insert PGA2040 onto it. ***Pay close attention to the orientation of the PGA2040.***  
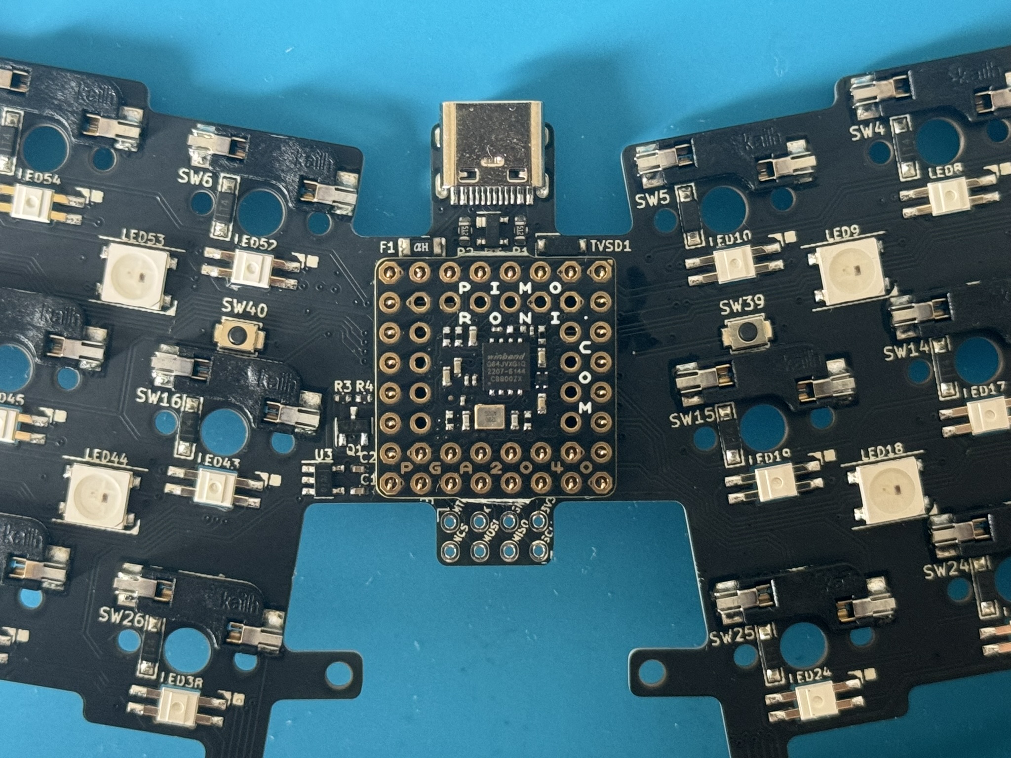
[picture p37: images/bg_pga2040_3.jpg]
  

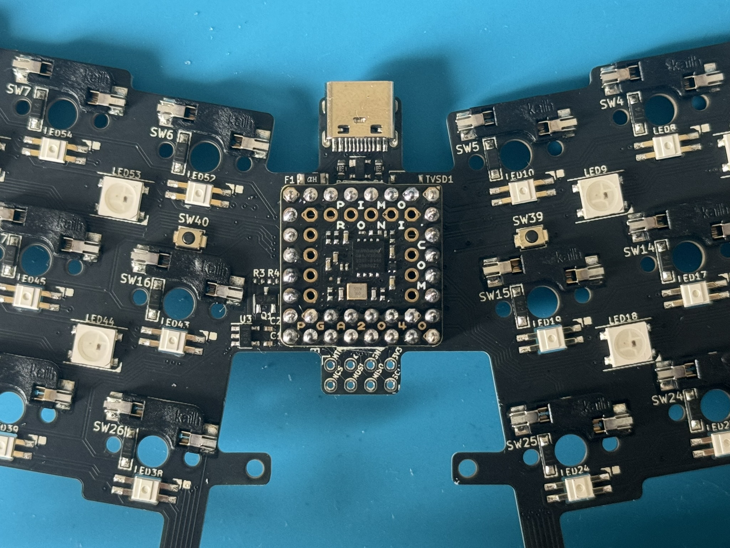
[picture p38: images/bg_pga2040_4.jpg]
  Check that the spring pin headers and PGA2040 are not floating, and solder for 34 pins on the PGA2040 side.　　

### Firmware

  After soldering the spring pin headers, plug the PGA2040 into the PCB and write the firmware.

  - Press the RESET button (SW39) while holding down the BOOT button (SW40) on the bottom side to enter boot loader mode.
  - The firmware is written by dragging and dropping the [.uf2](https://github.com/aki27kbd/cocot38mini/blob/main/firmware/v1/aki27_cocot38mini_vial.uf2) file into the drive named RPI-RP2.  
  cocot38mini_bg_  

  Keymap is editable from [vial](https://vial.rocks/).  
  You can confirm that trackball and LEDs are working correctly with this firmware. You can confirm the trackball move after you assemble the following steps.

  vial

  The default firmware enables "Auto Mouse Layer", with which you can automatically jump into a specific mouse layer when you move trackball. You can toggle on/off this function with the custom keycode `AM_TOG`.

  The source code is available [here](https://github.com/aki27kbd/vial-qmk/tree/vial/keyboards/aki27/cocot38mini).  

### Sensor PCB

  Place the mouse sensor (PMW3360) on the sensor board in the orientation shown in the picture. Please make sure to align the ● mark on the silk with the ● mark on the board.
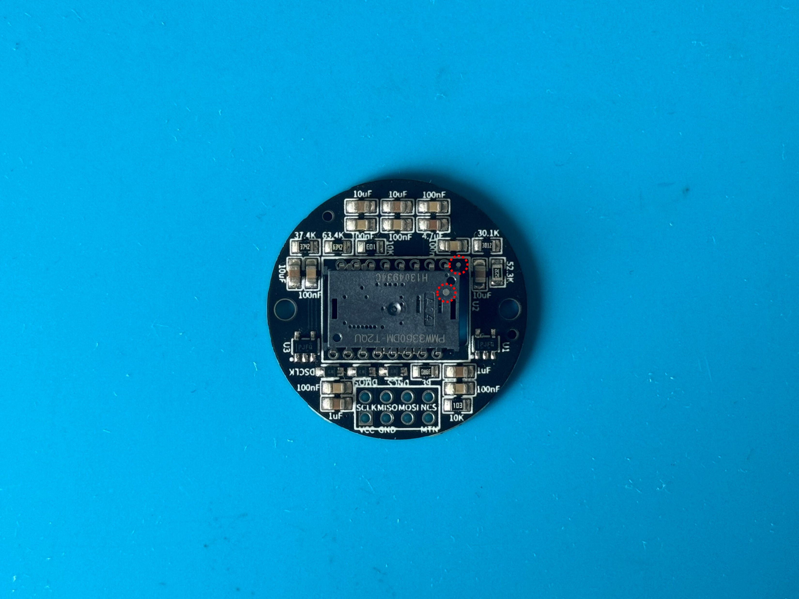
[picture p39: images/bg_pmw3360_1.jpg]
  

  With the sensor pins firmly in place, secure them with tape so that they do not float. Solder 16 pins from the top side. Remove tape from the sensor and attach the lens from the top side.   
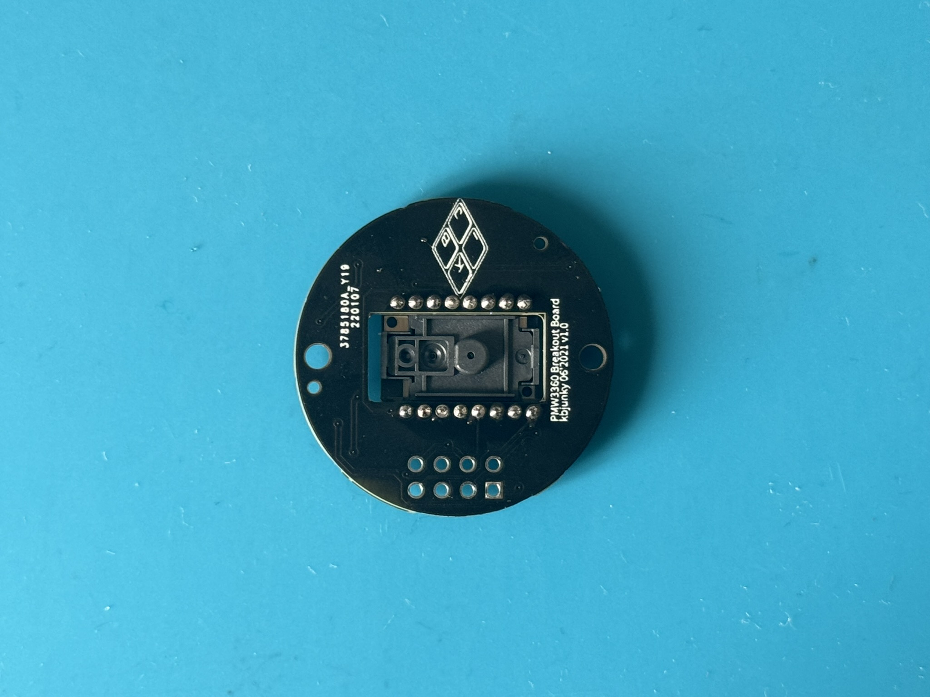
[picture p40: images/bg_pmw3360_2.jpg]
  

  Solder spring pin headers (or pin headers) to the Sensor PCB. In this buildguide spring pin headers are used as example, but you can follow the most steps when you use pin headers.

  Cut spring pin headers with a cutter knife and insert them into the bottom side of the PCB as shown in the picture below. The picture shows 2x4pins. Please make sure you insert them in the correct location.  
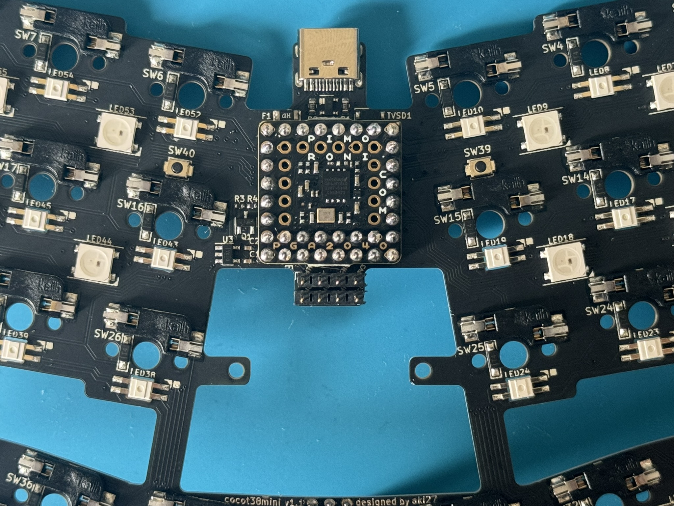
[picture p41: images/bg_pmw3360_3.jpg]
  

  Once you insert spring pin headers to the PCB, insert sensor PCB onto it. ***Pay close attention to the orientation of the sensor board.***  
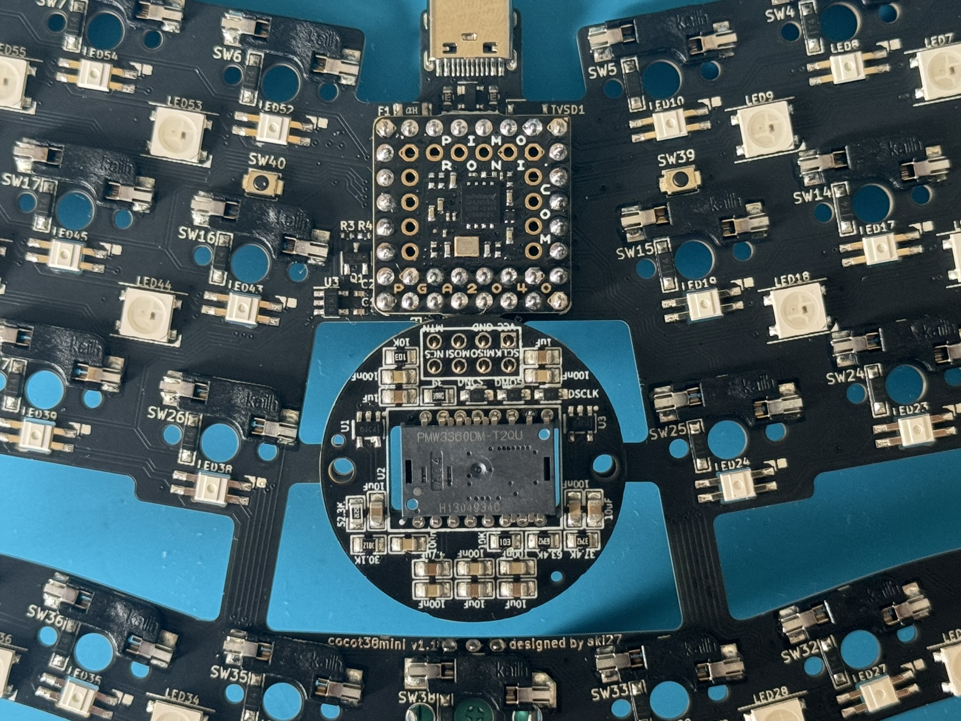
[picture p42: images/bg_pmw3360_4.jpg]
  

  Check that the spring pin headers and sensor board are not floating, and solder for 8 pins on the sensor board side.
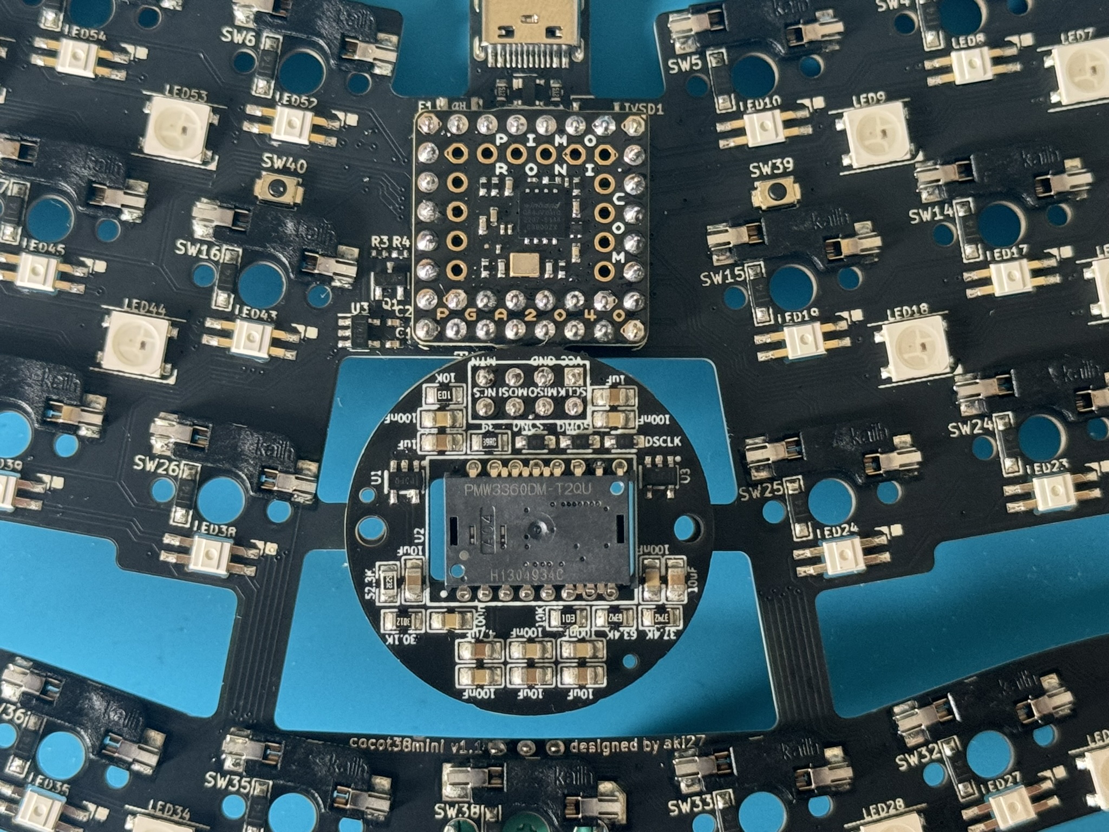
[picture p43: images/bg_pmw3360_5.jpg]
  

  Once you finish soldering, please confirm that mouse cursor moves when you move close to the sensor.

### Rotary Encoder (optional)

  If you prefer to using rotary encoder at the center of thumb clusters, insert a rotary encoder in the position shown in the picture and solder 5 pins from the bottom side.
  cocot38mini_bg_

### Zirconia Balls

  Glue the zirconia balls to the 3D printed top case using a two-component epoxy glue.  
  cocot38mini_bg_

  Take a small amount of glue on the tip of a toothpick or similar tool and apply it to the three depressions on the top case.  
  cocot38mini_bg_

  Insert zirconia balls into the depressions with glue and leave them until they harden. If the glue overflows into the surrounding area, wipe it off before it hardens. After the zirconia balls are glued, it will look like the picture below.  
  cocot38mini_bg_

### Assembly

  After soldering, stack the top case on top of the PCB and put key switches from the corners. Pay attention not bend the pins of the key switches.  
  cocot38mini_bg_

  cocot38mini_bg_

  Fit the top case and the bottom case together. First, align the bottom case so that the grooves on the bottom side of it (1&2) engages with the top case.  
  cocot38mini_bg_

  FIt the remaining grooves into the top case. Push in the order of 3>4>5 until they snap into the place. It will be easier to fit the bottom case into the top case if you push it while pulling the bottom case toward the far side.
  cocot38mini_bg_

  Put rubber feet on the bottom case.
  cocot38mini_bg_

  Put ball and keycaps, and take a photo.
  cocot38mini_bg_

## Custom Keycodes

  Several custom key codes can be set for trackball operation.

  Keycode   |Description
  ---------|-----------
  `CPI_SW`  |Change the CPI of the trackball. With the default firmware, each press changes the CPI in the following order: 200 -> 400 -> 800 -> 1600 -> 3200 -> 200....
  `SCRL_SW` |Changes the sensitivity of the sensor in scroll mode. The higher the value, the smaller the amount of scrolling.
  `ROT_R15` |Turns the Y axis of the mouse sensor 15 degrees clockwise.
  `ROT_L15` |Rotate the Y axis of the mouse sensor 15 degrees counterclockwise.
  `SCRL_MO` |	Enables scroll mode for as long as it is pressed.
  `SCRL_TO` |Toggles between scroll mode and mouse mode each time it is pressed.
  `SCRL_IN` |Inverts the scroll direction.
  `AM_TOG` |Toggle the function of auto mouse layer.

  Custom key codes can be set in vial using the custom key code under the User tab.  
  CustomKeycode_rev

## Notes
If you have any problems, please contact us at[Twitter](https://twitter.com/aki27kbd).

Also, it would be very encouraging if you could upload the completed photos to social networking sites. (If you don't feel comfortable uploading your photos, you can send them directly to us via DM.)

The hashtag is #cocot38mini .

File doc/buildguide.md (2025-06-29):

# Build Guide

cocot38mini_main02

cocot38mini v2のビルドガイドになります。  
v1のビルドガイドはこちら（[JP](v1/buildguide.md) / [EN](v1/buildguide_en.md)）を参照してください。

cocot38miniは、cocotシリーズをベースによりコンパクトさを追求したモデルです。25mmトラックボール専用に設計されたカラムスタッガード30%キーボードで、専用の3Dプリントケースが用意されています。まず始めにこのビルドガイドを最後までよく読み、必要なものを揃えた上で組み立てに取り掛かってください。

## 部品
### キット付属品

|名前|数|備考|
|---|---|---|
|メインPCB|1枚||
|センサーPCB|1枚||
|マウスセンサー（PMW3360）|1個||
|ゴム脚|4個||
|ジルコニア球（2mm）|3個||

### キット以外に必要なもの

|名前|数|備考|
|---|---|---|
|3Dプリントケース（トップ・ボトム）|各1個|公開されている3Dデータを元に3Dプリントサービスに発注|
|キースイッチ|37 or 38個|MX互換|
|キーキャップ|37 or 38個|MX互換|
|ロータリーエンコーダ+ノブ（直径19mm以下）|1個|オプション|
|コンスルー or ピンヘッダ（高さ2.5mm）|ピン合計が20本以上必要||
|トラックボール（25mmボール）|1個||
|ベアリングローラー（内径3mm、外径6mm、厚さ2.5mm）|3個|オプション（ベアリングローラー支持）|
|タッドポール|8本|オプション（タッドポールマウント）|
|熱圧入インサートナット|8個|オプション（トップマウント）|
|M2ねじ3mm|8本|オプション（トップマウント）|
|USB-TypeCケーブル|1本||

## 組み立て
### 部品確認

  まずはキット付属品に記載されたパーツが揃っているか確認ください。  
  その他上述の「キット以外に必要なもの」を揃えた上で組み立てに取り掛かってください。

  - タブ付きPCBの場合にはタブを割って切り離し、切断面を軽くヤスリがけしてください。

### ファームウェア

  デフォルトのファームが書き込まれた状態でお届けしています。まず始めにセンサー基板をUSBに接続し、cocot38miniとして認識されることを確認してください。必ずはんだ付けを行う前にこのプロセスを実行してください。

  ご自分でファームを書き込む場合、下記手順の通り実行してください。

  - センサー基板のBOOTボタンを押しながらRESETボタンを押し、ブートローダーモードに入ります。
  - その状態でRPI-RP2というドライブに[.uf2](https://github.com/aki27kbd/cocot38mini/blob/main/firmware/aki27_cocot38mini_v2_vial.uf2)ファイルをドラッグ&ドロップすることでファームが書き込まれます。　　

  キーマップは[vial](https://vial.rocks/)から更新可能です。  
  トラックボールの動作は後述のセンサー基板を組み立ててから行ってください。  
  vial

  デフォルトのファームウェアでは自動マウスレイヤー機能がオンになっています。この機能では、トラックボールを動かすと自動的にマウスレイヤー（レイヤー4）に移動することが可能です。カスタムキーコード（`AM_TOG`）を押すことで自動マウスレイヤー機能のオンオフを切り替えられます。

  ソースコードは[こちら](https://github.com/aki27kbd/vial-qmk/tree/vial/keyboards/aki27/cocot38mini)を参照ください。         

### センサー基板

  センサー基板にマウスセンサー（PMW3360）を基板裏面から写真の向きに設置し、表面からはんだ付けを行います。シルクの●印と基板の●印の位置が合うように注意してください。    
  cocot38mini_bg_

  センサーの脚がしっかり奥まで入った状態で、浮かないようにマスキング テープなどで固定します。  
  表面から16本の脚をはんだ付けします。センサーに貼られているテープを剥がし、表面からレンズを付けます。    
  cocot38mini_bg_

  はんだ付け後、USBに接続し、センサー近くで指をかざしてカーソルが動くか確認してください。

### コンスルー /  ピンヘッダ

  ここではコンスルーを例として扱いますが、ピンヘッダを用いる場合も基本的には同様です。

  コンスルー（高さ2.5mm）をカッターナイフなどで切り分け、下の写真のようにセンサー基板表面に差し込みます。本数や向きの組み合わせは多少写真と異なっていても問題ありません。（写真では7ピン×2本、6ピン×1本としています。）コンスルーを差し込むピンの位置を間違えないように注意してください。  
  cocot38mini_bg_

  cocot38mini_bg_

  コンスルーを差し込んだら、メイン基板を上から差し込みます。***各基板の向き（表裏・上下）に細心の注意を払ってください。***

  cocot38mini_bg_

### ロータリーエンコーダ（オプション）

  オプションのロータリーエンコーダを付ける場合は写真の位置に差し込み、裏側から5か所はんだ付けを行ってください。ロータリーエンコーダを搭載せずキースイッチを付ける場合はこの工程をスキップしてください。  
  cocot38mini_bg_

### トラックボール支持球

  3Dプリントトップケースにジルコニア球を接着します。2液混合エポキシ接着剤などをお使いください。  
  cocot38mini_bg_

  爪楊枝などの先に接着剤を適量取り、トップケースにある3か所の窪みに塗ります。  
  cocot38mini_bg_

  ジルコニア球を接着剤の付いた窪みにはめ込み、固まるまで放置します。  
  接着剤が周囲にあふれた場合は固まる前にふき取ってください。  
  ジルコニア球接着後は下記の写真のようになります。  
  cocot38mini_bg_

### 組み立て

  はんだ付けと動作確認が終わった基板をトップケースと重ね、四隅から順番にキースイッチをはめていきます。キースイッチの脚が曲がってしまわないように注意してください。また、基板がトップケースと密着するようにキースイッチをはめてください。  
  cocot38mini_bg_

  キースイッチがはめ終わった状態です。  
  cocot38mini_bg_

  トップケースとボトムケースをはめていきます。まずボトムケースの奥側の溝（写真①②）がトップケースとかみ合うように合わせてください。  
  cocot38mini_bg_

  ①②がはまった状態で、残りの溝をトップケースにはめていきます。③→④→⑤の順番にカチッとはまるまで押し込んでください。ボトムケースを①②側に寄せながら押し込むとはまりやすくなります。  
  cocot38mini_bg_

  ボトムケースがはまったら、ゴム脚を貼り付けます。
  cocot38mini_bg_

  ボール、キーキャップをはめて完成です。
  cocot38mini_bg_

## カスタムキーコード

  トラックボールの操作に関していくつかカスタムキーコードを設定することが可能です。（SCRL_MOはレイヤー4でのみ有効）

  Keycode   |Description
  ---------|-----------
  `CPI_SW`  |トラックボールのCPIを変更します。デフォルトのファームウェアでは、押すたびに200→400→800→1600→3200→200…という順番でCPIが変わります。
  `SCRL_SW` |スクロールモードにおけるセンサーの感度を変更します。数値が大きいほどスクロール量が小さくなります。
  `ROT_R15` |マウスセンサーのＹ軸を時計回りに15度回転させます。
  `ROT_L15` |マウスセンサーのＹ軸を反時計回りに15度回転させます。
  `SCRL_MO` |押されている間スクロールモードになります。（デフォルトファームではレイヤー4でのみ有効）
  `SCRL_TO` |押すたびにスクロールモードとマウスモードを切り替えます。（デフォルトファームでは無効）
  `SCRL_IN` |スクロール方向を反転させます。
  `AM_TOG` |自動マウスレイヤー切り替えのオンオフを切り替えます。

  vialでカスタムキーコードを設定する場合はUserタブ下のカスタムキーコードを用いて設定することが可能です。  
  CustomKeycode_rev

## 終わりに
何かトラブルがあれば[Twitterアカウント](https://twitter.com/aki27kbd)までご連絡ください。

また、完成写真をSNSにアップいただけるととても励みになります。（アップするのがはばかられる方はDMで直接送りつけていただいても構いません。）

ハッシュタグは #cocot38mini です。

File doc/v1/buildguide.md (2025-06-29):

# Build Guide

cocot38mini_main02

cocot38mini v1のビルドガイドになります。  
v2のビルドガイドはこちら（[JP](/doc/buildguide.md) / [EN](/doc/buildguide_en.md)）を参照してください。

cocot38miniは、cocotシリーズをベースによりコンパクトさを追求したモデルです。25mmトラックボール専用に設計されたカラムスタッガード30%キーボードで、専用の3Dプリントケースが用意されています。まず始めにこのビルドガイドを最後までよく読み、必要なものを揃えた上で組み立てに取り掛かってください。

## 部品
### キット付属品

|名前|数|備考|
|---|---|---|
|メインPCB|1枚||
|センサーPCB|1枚||
|マウスセンサー（PMW3360）|1個||
|PGA2040|1個||
|ゴム脚|4個||
|ジルコニア球（2mm）|3個||

### キット以外に必要なもの

|名前|数|備考|
|---|---|---|
|3Dプリントケース（トップ・ボトム）|各1個|公開されている3Dデータを元に3Dプリントサービスに発注|
|キースイッチ|37 or 38個|MX互換|
|キーキャップ|37 or 38個|MX互換|
|ロータリーエンコーダ+ノブ（直径19mm以下）|1個|オプション|
|コンスルー or ピンヘッダ（高さ2.5mm）|ピン合計が42本以上必要||
|トラックボール（25mmボール）|1個||
|USB-TypeCケーブル|1本||

## 組み立て
### 部品確認

  まずはキット付属品に記載されたパーツが揃っているか確認ください。  
  その他上述の「キット以外に必要なもの」を揃えた上で組み立てに取り掛かってください。

  - タブ付きPCBの場合にはタブを割って切り離し、切断面を軽くヤスリがけしてください。

### PGA2040

  PGA2040にコンスルー（or ピンヘッダ）をはんだ付けします。ここではコンスルーを例として扱いますが、ピンヘッダを用いる場合も基本的には同様です。

  コンスルー（高さ2.5mm）をカッターナイフなどで切り分け、下の写真のようにPCB裏面に差し込みます。本数や向きの組み合わせは多少写真と異なっていても問題ありません。（写真では8ピン×2本、6ピン×3本としています。）コンスルーを差し込むピンの位置を間違えないように注意してください。  
  cocot38mini_bg_

  cocot38mini_bg_

  コンスルーを差し込んだら、PGA2040を上から差し込みます。***PGA2040の向き（表裏・上下）に細心の注意を払ってください。***  
  cocot38mini_bg_

  コンスルー、PGA2040が浮いていないか確認し、PGA2040側の34ピン分はんだ付けを行ってください。
  cocot38mini_bg_

### ファームウェア

  コンスルーのはんだ付けが終わったら、PGA2040をPCBに差し込み、ファームウェアの書き込みを行います。

  - 裏面のBOOTボタン（SW40）を押しながらRESETボタン（SW39）を押し、ブートローダーモードに入ります。
  - その状態でRPI-RP2というドライブに[.uf2](https://github.com/aki27kbd/cocot38mini/blob/main/firmware/v1/aki27_cocot38mini_vial.uf2)ファイルをドラッグ&ドロップすることでファームが書き込まれます。　　
  cocot38mini_bg_  

  キーマップは[vial](https://vial.rocks/)から更新可能です。  
  トラックボール、LED含めて上記.uf2ファイルで確認いただけます。
  トラックボールの動作は後述のセンサー基板を組み立ててから行ってください。  
  vial

  デフォルトのファームウェアでは自動マウスレイヤー機能がオンになっています。この機能では、トラックボールを動かすと自動的にマウスレイヤー（レイヤー4）に移動することが可能です。カスタムキーコード（`AM_TOG`）を押すことで自動マウスレイヤー機能のオンオフを切り替えられます。

  ソースコードは[こちら](https://github.com/aki27kbd/vial-qmk/tree/vial/keyboards/aki27/cocot38mini)を参照ください。      

### センサー基板

  センサー基板にマウスセンサー（PMW3360）を基板裏面から写真の向きに設置し、表面からはんだ付けを行います。シルクの●印と基板の●印の位置が合うように注意してください。    
  cocot38mini_bg_

  センサーの脚がしっかり奥まで入った状態で、浮かないようにマスキング テープなどで固定します。  
  表面から16本の脚をはんだ付けします。センサーに貼られているテープを剥がし、表面からレンズを付けます。    
  cocot38mini_bg_

  次にセンサー基板にコンスルー（or ピンヘッダ）をはんだ付けします。ここではコンスルーを例として扱いますが、ピンヘッダを用いる場合も基本的には同様です。

  コンスルー（高さ2.5mm）をカッターナイフなどで切り分け、下の写真のようにPCB裏面に差し込みます。本数や向きの組み合わせは多少写真と異なっていても問題ありません。コンスルーを差し込むピンの位置を間違えないように注意してください。  
  cocot38mini_bg_

  コンスルーを差し込んだら、センサー基板を上から差し込みます。***センサー基板の向き（表裏・上下）に細心の注意を払ってください。***  
  cocot38mini_bg_

  コンスルー、センサー基板が浮いていないか確認し、センサー基板側の8ピン分はんだ付けを行ってください。
  cocot38mini_bg_

  はんだ付け後、センサー基板をPCBに差し込み、センサー近くで指をかざしてカーソルが動くか確認してください。

### ロータリーエンコーダ（オプション）

  オプションのロータリーエンコーダを付ける場合は写真の位置に差し込み、裏側から5か所はんだ付けを行ってください。ロータリーエンコーダを搭載せずキースイッチを付ける場合はこの工程をスキップしてください。  
  cocot38mini_bg_

### トラックボール支持球

  3Dプリントトップケースにジルコニア球を接着します。2液混合エポキシ接着剤などをお使いください。  
  cocot38mini_bg_

  爪楊枝などの先に接着剤を適量取り、トップケースにある3か所の窪みに塗ります。  
  cocot38mini_bg_

  ジルコニア球を接着剤の付いた窪みにはめ込み、固まるまで放置します。  
  接着剤が周囲にあふれた場合は固まる前にふき取ってください。  
  ジルコニア球接着後は下記の写真のようになります。  
  cocot38mini_bg_

### 組み立て

  はんだ付けと動作確認が終わった基板をトップケースと重ね、四隅から順番にキースイッチをはめていきます。キースイッチの脚が曲がってしまわないように注意してください。また、基板がトップケースと密着するようにキースイッチをはめてください。  
  cocot38mini_bg_

  キースイッチがはめ終わった状態です。  
  cocot38mini_bg_

  トップケースとボトムケースをはめていきます。まずボトムケースの奥側の溝（写真①②）がトップケースとかみ合うように合わせてください。  
  cocot38mini_bg_

  ①②がはまった状態で、残りの溝をトップケースにはめていきます。③→④→⑤の順番にカチッとはまるまで押し込んでください。ボトムケースを①②側に寄せながら押し込むとはまりやすくなります。  
  cocot38mini_bg_

  ボトムケースがはまったら、ゴム脚を貼り付けます。
  cocot38mini_bg_

  ボール、キーキャップをはめて完成です。
  cocot38mini_bg_

## カスタムキーコード

  トラックボールの操作に関していくつかカスタムキーコードを設定することが可能です。（SCRL_MOはレイヤー4でのみ有効）

  Keycode   |Description
  ---------|-----------
  `CPI_SW`  |トラックボールのCPIを変更します。デフォルトのファームウェアでは、押すたびに200→400→800→1600→3200→200…という順番でCPIが変わります。
  `SCRL_SW` |スクロールモードにおけるセンサーの感度を変更します。数値が大きいほどスクロール量が小さくなります。
  `ROT_R15` |マウスセンサーのＹ軸を時計回りに15度回転させます。
  `ROT_L15` |マウスセンサーのＹ軸を反時計回りに15度回転させます。
  `SCRL_MO` |押されている間スクロールモードになります。（デフォルトファームではレイヤー4でのみ有効）
  `SCRL_TO` |押すたびにスクロールモードとマウスモードを切り替えます。（デフォルトファームでは無効）
  `SCRL_IN` |スクロール方向を反転させます。
  `AM_TOG` |自動マウスレイヤー切り替えのオンオフを切り替えます。

  vialでカスタムキーコードを設定する場合はUserタブ下のカスタムキーコードを用いて設定することが可能です。  
  CustomKeycode_rev

## 終わりに
何かトラブルがあれば[Twitterアカウント](https://twitter.com/aki27kbd)までご連絡ください。

また、完成写真をSNSにアップいただけるととても励みになります。（アップするのがはばかられる方はDMで直接送りつけていただいても構いません。）

ハッシュタグは #cocot38mini です。

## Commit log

2025-05-02 add case data for v2
    [cocot38mini_bottom_v4.stp, cocot38mini_top_v5.stp, cocot38mini_v2_bottom.stp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]
2025-05-14 prepare for v2
    [cocot38mini_bottom_v1.stp, cocot38mini_top_v1.stp]
2025-05-15 add v2 cases
    [cocot38mini_v2_ballcover.stp, cocot38mini_v2_bottom.stp, cocot38mini_v2_integrated_top_claw.stp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]
2025-05-16 add description for bearing assembly
2025-05-16 add description for resin case for top mount
2025-06-06 add thick plate and large snap fit
    [cocot38mini_v2_tadpole_plate_thick.stp, cocot38mini_v2_tadpole_top_magnet_Lsnap.stp]
